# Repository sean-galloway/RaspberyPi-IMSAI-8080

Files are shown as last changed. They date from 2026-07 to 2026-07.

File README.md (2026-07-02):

# IMSPI 8080

A smart front panel for a 10" rack, styled after the IMSAI 8080, driven by a
Raspberry Pi (running an 8080/Z80 emulator such as z80pack or SIMH) over a single
USB link. An on-panel RP2040 owns all LED refresh and switch debounce and exposes
the panel to the Pi as a small register-mapped serial peripheral.

## Why a smart panel

The naive build wires every LED and switch straight back to the Pi header with
flying leads — which does not scale past ~60 I/O and turns into a harness. Instead
the panel carries its own microcontroller and driver silicon, and the Pi talks to
it the way a CPU talks to memory-mapped I/O: write the lamp registers, read the
switch registers. This decouples the panel's real-time refresh from whatever else
the Pi is doing, moves debounce and PWM off the Pi, and keeps a single 3.3V rail
with no level shifters.

## Panel layout

Matched to the physical panel (see `docs/panel-layout.svg`):

- Left block: three rows of 8 LEDs over 8 toggles
  - row 1 — address high (A15..A8)
  - row 2 — address low  (A7..A0)
  - row 3 — data          (D7..D0)
  - 8 data toggles (latching) below
- Right block: one row of 4 status LEDs over 4 command switches (momentary)

28 LEDs, 12 switches, sized to the ~220 mm usable width of a 10" rack aperture.
Because all 16 address bits are displayed even though only 8 data toggles exist,
EXAMINE looks fully authentic; address entry is byte-wise (see `docs/protocol.md`).

## Architecture

```
  Raspberry Pi 5 ── USB CDC ── RP2040 (Pico) ─┬─ SPI ──▶ 2x TLC5947  ─▶ 28 LEDs
   (emulator)                                  └─ GPIO ─▶ 2x 74HC165 ◀─ 12 switches
```

- MCU: RP2040 (Raspberry Pi Pico / Pico 2)
- LED driver: 2x TLC5947 (24ch, 12-bit PWM, constant current) daisy-chained -> 48ch, 28 used
- Switch input: 2x 74HC165 (parallel-in serial-out) daisy-chained -> 16 in, 12 used
- Link: RP2040 native USB CDC (`/dev/ttyACM0`); 4-pin UART is the wired fallback

See `docs/bom.md` for the parts list and `docs/panel-layout.md` for the bezel grid
and pitch math.

## Repo layout

```
docs/        protocol spec, BOM, panel layout + drawing
firmware/    RP2040 firmware (Pico SDK, C)
host/        Python driver + examples for the Pi side
hardware/    KiCad / mechanical notes
```

## Quick start

Firmware: see `firmware/README.md` (Pico SDK build -> drag `imspi8080.uf2` to the
Pico in BOOTSEL mode).

Host: see `host/README.md`.

```bash
cd host
pip install -e .
python examples/lamp_test.py /dev/ttyACM0
```

## Emulator integration

The panel is a clean memory-mapped-I/O seam. On each emulated CPU step, write the
LED frame (address bus, data bus, status flags) and consume any latched switch
events. z80pack and SIMH both expose CPU state and an I/O hook you can bridge to
`host/imspi`; `examples/panel_demo.py` drives the panel with a synthetic bus so you
can validate the hardware end-to-end before wiring the emulator.

## License

MIT — see `LICENSE`.

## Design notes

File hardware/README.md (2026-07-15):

# Hardware

IMSPI 8080 front-panel PCB + 3D-printed fascia for the 10" rack.

## ⬆️ To send to the fab, upload ONE folder: `jlcpcb-rev3/`

That is the only current, DRC-clean package. Everything superseded lives in `OLD/`.

```
jlcpcb-rev3/
  imspi8080-rev3-gerbers.zip   <- upload this (copper/mask/silk/paste + PTH & NPTH drill)
  imspi8080-rev3-cpl.csv       <- placement (83 SMT parts)
  imspi8080-rev3-bom.csv       <- BoM (electronics only; switches are hand-jumpered)
  README.txt                   <- step-by-step upload order + gotchas
```

Board: **204 × 99.7 mm**, 2-layer, 1.6 mm FR-4. Fully routed, 0 unconnected, 0 DRC errors.

## Current rev3 source (the design behind that package)

| File | What it is |
|---|---|
| `imspi8080_rev3.kicad_pcb` | the board (+ `.dsn`/`.ses` routing, `.kicad_pro`/`.prl`) |
| `rev3_place2.py` → `rev3_pads.py` | build chain: signal-flow placement, then bottom-edge switch landing pads |
| `rev3_routed.png` | routed board render |
| `faceplate/` | 3D-printed fascia — `gen_faceplate_3d.py` → `faceplate_3d.scad`/`.stl`, `faceplate_preview.png` |
| `design-spec.md`, `bom.csv`, `imspi8080_skidl.py` | design notes / schematic source |

**Switch scheme (rev3):** panel toggles mount on the fascia just below the board's
bottom edge and jumper straight up to a labeled solder landing-pad cluster each
(`SWD0-7` data 1×3, `SWC0-3` command 2×3; back-silk `V/Sn/G`, `Cn/G`). No connectors,
no cables, no board cutouts. The switch pads are bare/hand-soldered, so they are
excluded from the CPL/BoM.

## `OLD/` — superseded, do NOT upload

- `jlcpcb-rev1/`, `jlcpcb-rev2/` — earlier fab packages (rev1 is the one already ordered)
- `imspi8080_rev2.*`, `imspi8080.*` — earlier boards
- `rev3_voids.py`, `rev3_back.png` — the abandoned "switch-through-void" design
- earlier placement scripts, logs, notes

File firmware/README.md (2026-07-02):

# IMSPI 8080 firmware (RP2040)

Owns LED refresh (2x TLC5947), switch scan + debounce (2x 74HC165), and the
serial protocol to the Pi over native USB CDC. Built with the Raspberry Pi
Pico SDK.

## Prerequisites

- CMake >= 3.13, GNU Arm toolchain, and the Pico SDK.
- Set `PICO_SDK_PATH` to your SDK checkout, e.g.:

```bash
git clone https://github.com/raspberrypi/pico-sdk.git
cd pico-sdk && git submodule update --init && cd ..
export PICO_SDK_PATH=$PWD/pico-sdk
```

## Build

```bash
cd firmware
mkdir build && cd build
cmake ..
make -j
```

This produces `build/imspi8080.uf2`. Hold BOOTSEL on the Pico, plug it in, and
drag the `.uf2` onto the `RPI-RP2` drive.

## Wiring

Pin assignments are in `src/config.h` (RP2040 GPIO numbers). Defaults:

| Signal | GPIO | To |
|---|---|---|
| TLC SIN | 3 | first TLC5947 SIN |
| TLC SCLK | 2 | TLC5947 SCLK  |
| TLC XLAT | 4 | TLC5947 XLAT  |
| TLC BLANK | 5 | TLC5947 BLANK |
| TLC GSCLK | 6 | TLC5947 GSCLK |
| HC165 SH/LD | 10 | 74HC165 pin 1 |
| HC165 CLK | 11 | 74HC165 pin 2 |
| HC165 QH | 12 | last 74HC165 QH |

If the wrong LED chip lights up, flip `TLC_REVERSE_DEVICE_ORDER`. If switches map
backwards, flip `HC165_REVERSE_BITS`.

## Notes and things to verify against the datasheet

- The TLC5947 GSCLK is a free-running PWM (`TLC_GSCLK_HZ`, default 1 MHz) and
  BLANK is released after priming. For flicker-free updates you can additionally
  pulse BLANK once per 4096 GSCLK cycles to align the grayscale counter — not
  required for a front panel, but noted.
- Data shift is bit-banged for clarity. If you want more headroom, move SIN/SCLK
  onto a hardware SPI instance; the byte order in `tlc5947.c` stays the same.
- CRC-8 parameters must stay in sync with `host/imspi/crc8.py`.

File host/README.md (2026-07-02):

# IMSPI 8080 host driver

Python driver for the Pi side of the panel. Talks the serial protocol in
`../docs/protocol.md` to the RP2040 over USB CDC (`/dev/ttyACM0`).

## Install

```bash
cd host
python -m venv .venv && source .venv/bin/activate
pip install -e .
```

## Use

```python
from imspi import Panel

with Panel("/dev/ttyACM0") as p:
    print(p.ping())                       # (major, minor)
    p.set_bus(addr=0x1234, data=0x76, status=0b0001)  # RUN lamp on
    rep = p.poll(timeout=1.0)             # latest SwitchReport, or None
    if rep and rep.examine:               # command switch 2 (EXAMINE) pressed
        print("examine, data toggles =", hex(rep.data))
```

## Examples

```bash
python examples/lamp_test.py /dev/ttyACM0     # bring-up: sweep lamps, print switches
python examples/panel_demo.py /dev/ttyACM0    # synthetic bus + live switch echo
```

`panel_demo.py` drives the panel with a fake address/data bus and mirrors the data
toggles onto the data lamps, so you can validate the whole panel before wiring an
emulator. For z80pack/SIMH, replace the synthetic loop with the emulator's CPU
state and feed switch events back into its I/O hook.

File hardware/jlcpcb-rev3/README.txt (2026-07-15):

IMSPI 8080 rev3 — JLCPCB upload package
=======================================
Board: 204 x 99.7 mm, 2-layer, 1.6 mm FR-4, HASL. 83 SMT parts.
Fully routed, DRC-clean (0 unconnected, 0 errors).

WHAT'S DIFFERENT FROM REV1/REV2
- The panel switches are NOT on a separate bracket wired through JST connectors
  (rev1/rev2 J3/J4). Instead each switch has its own labeled solder LANDING-PAD
  cluster along the board's BOTTOM EDGE:
    SWD0..7 : 1x3 pads [V=+3V3, Sn=data common, G=GND]  (MTS-123 SPDT data toggles)
    SWC0..3 : 2x3 pads [Cn=cmd common, G=GND, +4 spare]  (MTS-223 DPDT command toggles)
  The switches mount on the fascia just below the board and jumper straight up to
  these pads. Back-silk labels every pad. These pads are BARE — hand-soldered — so
  they are excluded from the CPL/BoM (JLCPCB places nothing there).

UPLOAD ORDER
1. jlcpcb.com -> Add Gerber -> upload  imspi8080-rev3-gerbers.zip
   (auto-detects 2-layer, 204 x 99.7 mm)
2. Enable SMT Assembly -> "Assemble both sides".
3. Placement file (CPL):  imspi8080-rev3-cpl.csv   (Designator, Mid X, Mid Y, Layer, Rotation)
4. BOM:                   imspi8080-rev3-bom.csv   (83 placed parts)
5. Step through part matching; confirm each turns green. U2 flash must be the 3.3 V
   part (W25Q128JVSIQ, not the 1.8 V JW). Verify pin-1 rotations in the preview.

NOTES
- Ground is routed as traces (no plane) - fine for this low-speed panel.
- Mounting holes H1-H6 are NPTH and excluded from the CPL (correct).
- The 12 switch landing pads (SWD0-7, SWC0-3) are hand-jumpered to fascia toggles
  and are intentionally absent from the CPL/BoM.

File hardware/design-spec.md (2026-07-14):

# IMSPI 8080 controller board — design spec

Everything needed to lay the board out in KiCad and generate the manufacturing
files. Pair this with `bom.csv`. The BOM is upload-ready; the Gerbers and CPL
come out of the layout step described here.

## Board

- Panel format: **3U 10" rack face** (133.4 mm tall). 3U (not 2U) is required for
  mechanical clearance: the bezel toggles are panel-mounted with ~13 mm-deep bodies that
  stick back toward the PCB, so they ride on their own bracket below the board, wired back
  via J3/J4. (Trade-off: a 3U face reads squarer than the IMSAI's wide 2.5:1 — a fully
  faithful build wants a 19" 4U panel; see the project TODO.)
- Outline: **204 × 60 mm PCB (rev2)** — trimmed 10 mm on each axis from the rev1 214 × 70.
  The trim is **structural, not cosmetic**: it opens ~8-10 mm **clearance channels down
  each side** (and frees the band below) for the computer-carrier-plate side flanges, the
  front L-gussets, and their rail-mount hardware (see `carrier-plate-rigidity` plan and
  `TODO.md`). The 28 LEDs occupy the top ~32 mm; the ICs/connectors fill the band below.
- Stackup: 2-layer FR-4, 1.6 mm, HASL (ENIG optional for the HTSSOP pads).
- Mounting: 6× M2.5 to short bezel standoffs (see "Mounting holes" below). The outer hole
  columns (x = 8 / 196 mm) sit on the structural channels so the front L-gussets land on them.
- Assembly: two-sided SMT. Front (component/bezel side) carries the LEDs, ICs, and
  connectors; the 40 decoupling caps / resistors sit on the **back** directly under
  their ICs (ideal decoupling, GND pads land straight in the back ground plane, and
  the dense front layout de-clutters). Toggles remain off-board (wired). The small
  JLCPCB two-sided-assembly adder buys a far cleaner, routable board.

> **Rev1 (214 × 70) is already fabricated/ordered — the 204 × 60 numbers here define rev2.**
> The LED grid moved inward with the trim, so `docs/panel-layout.md` and the faceplate
> bezel windows must be regenerated to match before the faceplate is cut.

## Mounting holes

6× M2.5, NPTH, ~2.7 mm drill, electrically isolated (single-point ground kept
clean). Each gets a ~6 mm keep-out ring — no traces, pours, or parts inside it,
so the screw head/standoff base has room. Positions in mm from the board's
top-left datum (same datum as the LED grid), in LED-free zones, with the outer
columns on the structural side channels (204 × 60 rev2 board):

| Ref | X | Y  | Zone |
|-----|-----|----|---|
| H1  | 8 | 7  | top-left channel (gusset column)  |
| H2  | 131 | 7  | top, inter-block gap |
| H3  | 196 | 7  | top-right channel (gusset column) |
| H4  | 8 | 53 | bottom-left channel |
| H5  | 131 | 53 | bottom, inter-block gap |
| H6  | 196 | 53 | bottom-right channel |

Outer columns x = 8 / 196 → mirrored ~8 mm channels each side, and they are the
lines the carrier-plate front L-gussets bolt to. The mid-span holes (H2/H5) live
in the 119..147 mm gap between the left LED block (ends x=119) and the status
block (starts x=147) — keeping the strip from bowing without crowding any lamp.
Placed by `place_holes.py`, which offsets from the Edge.Cuts bbox so it is immune
to where the board sits on the sheet. Standoffs: short, **3–5 mm** brass, so the
LEDs sit just behind the bezel windows. Keep the tall parts (USB-C, microSD, JST)
at the edges, which the layout already does.

## Power tree

Two USB-C inputs, grounds bonded, 5 V rails separate.

```
USB-C #1 (J1)  VBUS 5V ──► U8 AMS1117-3.3 ──► 3V3_LOGIC ──► RP2040 IOVDD/USB/ADC,
   │                                                          TLC5947 VCC (logic),
   │ D+/D- (27R series) ──► RP2040 USB                        74HC165 VCC, SD VDD,
   │ CC1/CC2 ──► 5.1k to GND                                  pull-ups
   └ GND ──────────────────────────────┐
                                        ├── common GND
USB-C #2 (J2)  VBUS 5V ──► U9 AMS1117-3.3 ──► 3V3_LED ──► 28x LED anodes
   │ CC1/CC2 ──► 5.1k to GND            │
   └ GND ───────────────────────────────┘   (LED cathodes sink into TLC5947 → GND)
```

- RP2040 core (1.1 V) is generated by its internal LDO — just decouple DVDD.
- 3V3_LED at 3.3 V (not 5 V) keeps TLC5947 dissipation low: ~1.3 V drop/channel
  instead of ~3 V. If you ever want brighter lamps off the Pi's budget, J2 is a
  dedicated feed so the LED current never touches the logic side.
- Bulk 10 µF on each of: 3V3_LOGIC, 3V3_LED, and VBUS(J1). 100 nF at every IC.

## Net / connection map (RP2040 GPIO)

Dedicated-function pins (USB, QSPI, XIN/XOUT, SWD) per the RP2040 reference
design. Peripheral GPIO assignment:

| GPIO | Net | To |
|---|---|---|
| GP2 | TLC_SCLK | U3/U4 SCLK (SPI0 SCK) |
| GP3 | TLC_SIN | U3 SIN (SPI0 TX); U3 SOUT→U4 SIN|
| GP4 | TLC_XLAT | U3/U4 XLAT |
| GP5 | TLC_BLANK | U3/U4 BLANK |
| GP6 | TLC_GSCLK | U3/U4 GSCLK (PWM) |
| GP7 | HC_PLOAD | U5/U6 SH/LD |
| GP8 | HC_CLK | U5/U6 CLK |
| GP9 | HC_QH | U6 QH (chain output) |
| GP10 | SD_SCK | U7 CLK (SPI1 SCK) |
| GP11 | SD_MOSI | U7 CMD (SPI1 TX) |
| GP12 | SD_MISO | U7 DAT0 (SPI1 RX) |
| GP13 | SD_CS | U7 DAT3/CS (SPI1 CSn) |
| GP14-22| spare | broken out to J5 area / testpoints |

TLC5947 drivers share one SPI0 daisy-chain; the two 74HC165s share a bit-banged
chain; the SD card is on its own SPI1 so a card access can't stall lamp refresh.

### LED channel map (into the TLC5947 chain)

- U3 (device 0): ch0-7 = addr A15..A8, ch8-15 = addr A7..A0, ch16-23 = data D7..D0
- U4 (device 1): ch24-27 = status 0..3 (ch28-47 spare)

### Switch header pinout

J3 — data bank (S10B-XH-A), MTS-102 SPDT ON-ON, each common → 74HC165 input,
throws bussed to 3V3/GND at the bezel (no pull-ups needed):

```
1:3V3  2:SW0  3:SW1  4:SW2  5:SW3  6:SW4  7:SW5  8:SW6  9:SW7  10:GND
```

J4 — command bank (S6B-XH-A), MTS-123 center-off momentary, each common →
74HC165 input, one throw bussed to GND at the bezel; **pull-ups on-board** (R
group) define the released state:

```
1:GND  2:CMD0  3:CMD1  4:CMD2  5:CMD3  6:spare
```

Both are side-entry (right-angle) so the wire housings mate parallel to the
board — place them along the bezel-facing edge, openings outward.

## Layout plan

1. LEDs first, locked to the bezel grid from `docs/panel-layout.md` (3 rows of 8
   over the 8 data columns + 4 status), 15 mm column pitch (aligns lamps over toggles). Their positions are
   fixed by the bezel; everything else routes around them.
2. RP2040 + flash + crystal as a tight cluster (follow the reference layout;
   crystal and QSPI traces short). TLC5947s near the LED field to keep the 28
   LED-cathode traces short. 74HC165s near J3/J4.
3. USB-C J1 and J2 at accessible board edges (Pi cable to J1; LED supply to J2).
   microSD U7 at an edge with the slot opening reachable through a bezel cutout.
4. J3/J4 right-angle headers along the switch-facing edge.
5. Star the two 5 V rails; single solid ground pour bonding both USB-C grounds.

## Design rules (JLCPCB 2-layer, economy-safe)

- Trace/space ≥ 0.2 mm (0.15 mm capable if needed); LED-cathode and signal nets 0.25 mm.
- Via 0.3 mm drill / 0.6 mm pad; annular ring ≥ 0.13 mm.
- Board-edge clearance ≥ 0.3 mm; silkscreen ≥ 0.15 mm.
- Add fiducials (3× on the assembled side) for the pick-and-place.

## Manufacturing outputs (what to upload)

Ordered at **jlcpcb.com** ("Order Now" / Add Gerber). Three files:

1. **Gerbers ZIP** — from KiCad: Plot (all copper, mask, silk, edge cuts) +
   Generate Drill Files, zipped. *(produced by the layout step)*
2. **BOM CSV** — `hardware/bom.csv` in this repo. *(ready now)*
3. **CPL / pick-and-place CSV** — KiCad → Fabrication Outputs → Component
   Placement (.pos), columns Designator/Mid X/Mid Y/Rotation/Layer.
   *(produced by the layout step)*

At upload, toggle SMT Assembly, choose the assembled side (top), and step through
component matching — confirm each part turns green; watch for any LED or socket
flagged **Standard Only** (forces Standard PCBA) and swap if you want Economic.
Verify rotations in the placement preview (pin-1 dots) before paying.

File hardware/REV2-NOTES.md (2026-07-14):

# IMSPI 8080 — rev2 (204 × 60) re-layout

Rev2 trims the board 10 mm on each axis (rev1 was 214 × 70) to open the structural
side channels the computer-carrier-plate flanges/gussets need — see `design-spec.md`
and `../TODO.md`. **Rev1 is already fabricated/ordered; these are the rev2 files.**

## What's ready (generated headless)
| File | State |
|---|---|
| `imspi8080_rev2.kicad_pcb` | Board re-placed to 204 × 60 + **89/90 nets routed** |
| `rev2_place.py` | The placement driver (reproducible): resizes the outline, positions every footprint, rips up old routing. Run with `/usr/bin/python3 rev2_place.py` |
| `rev2_check.py` | Overlap / off-board checker (0 / 0 on the current board) |
| `imspi8080_rev2.dsn` / `.ses` | Specctra export + Freerouting result |
| `jlcpcb-rev2/imspi8080-rev2-cpl.csv` | Pick-and-place, 85 parts (45 top / 40 bottom), holes excluded |
| `jlcpcb-rev2/imspi8080-rev2-bom.csv` | BOM — **same 85 parts as rev1** (resize changes positions, not parts) |
| `place_leds.py`, `place_holes.py` | Updated to the rev2 grid (LEDs 14–119 / status 147–192, rows 6/18/30; holes 8/196) |

How it was built: `SKiDL netlist → rev2_place.py (placement) → Specctra DSN →
Freerouting 1.9.0 (headless, 0.15/0.13 mm rules) → SES import`. Placement is 0 overlaps,
0 off-board. Everything fits inside 204 × 60 with ~10 mm side channels.

## What YOU finish in KiCad (2 quick touch-ups, like rev1)
Open `imspi8080_rev2.kicad_pcb` in pcbnew, then:

1. **Route one trace** — the USB D− hop Freerouting couldn't thread through the RP2040's
   0.4 mm-pitch escape: **R6 pad 2 → U1 pad 46** (net `N$8`). Use the interactive router;
   it needs one via (R6 is on the back, U1.46 on the front). ~1 minute.
2. **Nudge one via** — the `SD_MISO` via near the bottom-right corner sits 0.18 mm from the
   board edge (rule is 0.3 mm). Drag it ~0.2 mm inward (KiCad will drag its tracks with it).
3. **DRC** → should be clean (Tools → DRC).
4. **Export fab**: Plot all copper + mask + silk + Edge.Cuts, Generate Drill Files, zip →
   Gerbers. Fabrication Outputs → Component Placement (.pos) → or just reuse
   `jlcpcb-rev2/imspi8080-rev2-cpl.csv`. BOM = `jlcpcb-rev2/imspi8080-rev2-bom.csv`.
5. **JLCPCB**: same as rev1 — **Standard PCBA, double-sided** (45 top + 40 back caps).

## BOM note (parts unchanged, but sync your JLCPCB swaps)
Resizing does **not** change the parts list. The rev2 BOM is the rev1 BOM. Separately,
the repo BOM still shows the *original* parts — it never got the JLCPCB replace-parts
swaps (SW1/SW2 → HX 3×4×2 tactile, U2 flash confirm, J5 DNP). Tell me your final choices
and I'll reconcile `bom.csv` + both fab BOMs.

## Faceplate (signage recesses)
`faceplate/gen_front_panel.py` (grabbed from jetson-marker-turret) regenerates
`faceplate/imspi_panel_front.svg` — the engraved legend + LED window slots (the paint
recesses), now **aligned to the rev2 LED grid**. Regenerate: `python3 gen_front_panel.py`.
The LED field is left-of-center after the trim (status block pulled in) — re-center by
adjusting `CONTENT_DX` if wanted (keep it in sync with the turret `rack_shelf.scad` mount).

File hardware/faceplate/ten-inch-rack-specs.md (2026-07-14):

# 10″ Rack — Panel & Mounting-Hole Specs

Reference for any front panel that mounts in the ground-station rack
(DeskPi RackMate T2, BOM #52). Use these numbers for rack-mount faces —
the compute shelf (#61), blank/vent panels (#59), and the IMSAI/IMSPI
fascia (built in the separate panel repo).

**Source:** manufacturer mechanical drawing, cross-checked against a real
10″ 12-port keystone patch panel (254 mm overall, 238 mm mount-hole span,
214 mm aperture). Confirm against your own rails before cutting — the oval
slots absorb small differences.

## Panel envelope

| Dimension | Value |
|---|---|
| Panel outer width | **254 mm** |
| 1U height | **44 mm** (1.73 in) |
| N-U panel height | **N × 44 mm** (2U = 88, 3U = 132) |
| Front-face thickness (printed) | 4–5 mm typical |

## Mounting-hole geometry

| Dimension | Value | Notes |
|---|---|---|
| Hole horizontal center-to-center | **238 mm** | across the panel |
| Hole inset from each **side** edge | **8 mm** | = (254 − 238) / 2 |
| Hole vertical center-to-center, **within 1U** | **33 mm** | |
| Hole inset from **top/bottom** of a 1U | **5.5 mm** | = (44 − 33) / 2 |
| Slot shape | **horizontal oval**, **9.33 W × 6.77 H mm** | oval = side-to-side rail-fit adjustment |

- Holes/slots come in a **column at x = 8 mm and x = 246 mm** (both side edges).
- Vertically they repeat per 1U: each 1U has a pair at **5.5 mm** from its top
  and bottom edges (33 mm apart).

## Clear aperture (usable opening)

| Face | Usable width | Usable height |
|---|---|---|
| any | **214 mm** | 1U ≈ 33 mm · 2U ≈ 77 mm · 3U ≈ 122 mm |

Width is set by the mounting-hole span, not the electronics.

## Worked example — a 3U face (132 mm tall)

Four corner mounting slots (what the compute-bay design uses):

| Slot | x (from left) | z (from bottom) |
|---|---|---|
| top-left | 8 | 126.5 |
| top-right | 246 | 126.5 |
| bottom-left | 8 | 5.5 |
| bottom-right | 246 | 5.5 |

(z = 5.5 from the bottom edge, and 132 − 5.5 = 126.5 from it for the top.)
If your rails are tapped at every U, you may add mid-height slots on the
same 33-mm-in-1U pattern; 4 corners is sufficient for a printed compute bay.

## OpenSCAD reference

```scad
// 10" rack mounting geometry
face_width    = 254;
U             = 44;
rail_hole_dx  = 238;                       // horizontal C-C
hole_cc_v     = 33;                         // vertical C-C within 1U
slot_w        = 9.33;                       // oval slot W
slot_h        = 6.77;                       // oval slot H
slot_side_ctr = (face_width - rail_hole_dx)/2;   // 8 mm
slot_tb_ctr   = (U - hole_cc_v)/2;               // 5.5 mm

// one horizontal oval slot, cut through a face of thickness `th` (bore along +Y)
module rack_slot(th, eps = 0.01) {
    off = (slot_w - slot_h)/2;
    hull() for (dx = [-off, off])
        translate([dx, -eps, 0]) rotate([-90,0,0])
            cylinder(h = th + 2*eps, d = slot_h, $fn = 48);
}

// 4 corner slots for a panel `panel_U` high, thickness `th`
module rack_slots_4corner(panel_U, th) {
    panel_h = panel_U * U;
    for (sx = [slot_side_ctr, face_width - slot_side_ctr])
        for (sz = [slot_tb_ctr, panel_h - slot_tb_ctr])
            translate([sx, 0, sz]) rack_slot(th);
}
```

## Notes

- **Oval, not round:** the horizontal ovals let the panel slide ±~1.5 mm to
  line up with imperfect rails — orient the long axis horizontal.
- **Fasteners:** M6 rack screws (with cage/clip nuts) are typical for these
  10″ racks; confirm your rack's thread/cage-nut style.
- **RackMate T2 interior depth:** ~260 mm (≈10.23″) — leave room behind the
  face for cabling/service loops.

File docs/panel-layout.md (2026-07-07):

# Panel layout

See `panel-layout.svg` for the drawing. This documents the dimensions behind it.

## Width budget

A 10" 1U rack aperture measures **214 mm** wide × 33 mm high (verified against an
actual 10" 12-port keystone patch panel: 254 mm overall, 238 mm mount-hole span,
214 mm aperture). Width is set by toggle finger-clearance, not the electronics —
the LEDs are trivial. **Height forces 2U:** the lamps-over-toggles stack needs the
~77 mm usable aperture of a 2U face; it does not fit 1U's 33 mm.

## Blocks

Left block (8 columns):

| Row | Lamps | Element |
|-----|---|---|
| 1 | 8 — address high A15..A8 | 3 mm LED |
| 2 | 8 — address low  A7..A0  | 3 mm LED |
| 3 | 8 — data D7..D0 | 3 mm LED |
| — | 8 — data toggles | latching toggle |

Right block (4 columns):

| Row | Lamps | Element |
|-----|---|---|
| 1 | 4 — status | 3 mm LED |
| — | 4 — command | momentary toggle |

## Pitch math (fits 214 mm × 2U)

Columns must align vertically (LEDs sit above toggles), so toggle pitch governs
each block's column spacing.

- toggle pitch: ~15 mm center-to-center (fits 8 + 4 toggles in the 10" width;
  MTS mini-toggle bodies clear at this pitch)
- left block, 8 columns: 7 x 15 mm = **105 mm** span
- right block, 4 columns: 3 x 15 mm = **45 mm** span
- remaining for center gap + two side margins: 214 - 105 - 45 = **64 mm**

Comfortable fit horizontally. Vertically, the LED rows use **12 mm** pitch (centers
at y = 10 / 22 / 34), so the three-row lamp field is ~30 mm; adding the toggle row
below plus a branding strip is why this is a **2U** face (~77 mm usable), not 1U.

## Mechanical: the standoff stack

The one dimension to get right before fabbing the PCB:

```
printed bezel  ─┐
                │  toggle bushing length  +  panel thickness
PCB (toggles) ──┘  must equal the PCB-to-bezel standoff height
```

Board-mounted toggles solder to the PCB; their threaded bushings pass through the
bezel. If the standoff height doesn't match the bushing length (minus bezel
thickness), the bushings either don't reach the front face or protrude too far.
LED body length sets the same constraint for the LED domes. Measure the exact
bushing length and paddle-cap depth of the toggles you buy, then set the standoff
height and bezel thickness to suit — there is no fixing this after fab.

## Bezel windows + diffuser film

Rather than 28 individual holes, cut one horizontal window slot per LED row and
back it with smoked/diffuser film — the lamps read as glowing dots and the film
hides the PCB, unlit LEDs, and traces when off ("black glass until lit").

Slot centers align with the LED rows, so they inherit the 15 mm grid. Coordinates
in mm on the shared datum (LED rows at y = 10 / 22 / 34; left block x = 15..120,
status block x = 160..205):

| Window | X span | Y center | Size (W × H) |
|---|---|---|---|
| Row 1 addr hi | 10 – 125 | 10 | ~115 × 6 mm |
| Row 2 addr lo | 10 – 125 | 22 | ~115 × 6 mm |
| Row 3 data | 10 – 125 | 34 | ~115 × 6 mm |
| Status | 155 – 210 | 22 | ~55 × 6 mm |

- 6 mm slot height leaves ~6 mm of bezel between rows (12 mm row pitch) — enough
  material to stay rigid on a printed face.
- Film: dark-tinted diffusing acrylic/polycarbonate or LED diffusion sheet,
  0.5–1 mm, cut ~5 mm oversize per window and bonded to the **back** of the bezel.
- Tint eats brightness — plan to lower the TLC5947 IREF resistor a little to push
  more per-LED current (free on the dedicated LED rail). Swatch-test tint darkness
  against a lit LED before committing: too dark = weak lamps, too light = board
  shows when off.
- Alternative: one big 115 × 30 mm window over all three left-block rows backed by
  film — simplest cut, but less rigid and loses the segmented IMSAI slot look.

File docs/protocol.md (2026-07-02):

# IMSPI 8080 serial protocol

Version 0.1.0

The Pi (host) and the panel (RP2040) exchange fixed, byte-oriented frames over the
RP2040's native USB CDC (or a 4-pin UART fallback). Baud is nominal over CDC.
The panel is treated as a register-mapped peripheral: the host writes lamp
registers, the panel reports switch registers.

## Framing

Every frame is:

```
[SOF] [CMD] [payload ...] [CRC8]
```

- `SOF` — start-of-frame, direction-specific (lets each side resync)
  - host -> panel: `0xA5`
  - panel -> host: `0x5A`
- `CMD` — command/response byte (see tables)
- `CRC8` — over every byte in the frame *except* the CRC byte itself
  (i.e. from `SOF` through the last payload byte)

Frame length is fixed per `CMD`, so a receiver reads `SOF`, then `CMD`, then the
known number of remaining bytes. On CRC failure or unknown `CMD`, discard bytes
until the next valid `SOF`.

### CRC8

CRC-8, polynomial `0x07`, init `0x00`, no input/output reflection, no final XOR
(the classic "CRC-8/SMBUS" parameters). Reference implementations:
`firmware/src/crc8.c` and `host/imspi/crc8.py` — they are byte-for-byte identical.

## Host -> panel commands

### `0x01` LED update (8 bytes)

Writes the full lamp state in one frame.

| Byte | Field | Meaning |
|---|---|---|
| 0 | `0xA5` | SOF |
| 1 | `0x01` | CMD |
| 2 | `ADDR_HI` | address bus A15..A8 (bit7 = A15) |
| 3 | `ADDR_LO` | address bus A7..A0 |
| 4 | `DATA` | data bus D7..D0 |
| 5 | `STATUS`  | status lamps, bits 0..3 used (see below) |
| 6 | `BRIGHT`  | global brightness 0..255 (maps to 12-bit)  |
| 7 | `CRC8` | |

`STATUS` bit assignment (default, firmware-configurable):

| bit | lamp |
|-----|---|
| 0 | RUN |
| 1 | WAIT |
| 2 | HLDA |
| 3 | INT/PWR|

### `0x02` lamp test (4 bytes)

`[0xA5][0x02][ON][CRC8]` — `ON != 0` drives all lamps full on; `0` returns to the
last LED-update state. Useful for bring-up and a boot self-test.

### `0x03` set brightness (4 bytes)

`[0xA5][0x03][LEVEL][CRC8]` — global brightness 0..255 without changing lamp state.

### `0x7F` ping (3 bytes)

`[0xA5][0x7F][CRC8]` — panel replies with `0xC0` version.

## Panel -> host responses

### `0x81` switch report (6 bytes)

Sent on any switch change and on a periodic heartbeat.

| Byte | Field | Meaning |
|---|---|---|
| 0 | `0x5A` | SOF |
| 1 | `0x81` | CMD |
| 2 | `SW_DATA` | 8 data toggle levels (bit i = toggle i) |
| 3 | `SW_CMD`  | 4 command switch levels, bits 0..3 |
| 4 | `EVENTS`  | latched rising edges on command switches 0..3 |
| 5 | `CRC8` | |

`SW_DATA` are latching toggles, reported as levels. The 4 command switches are
momentary (spring-return); their *levels* are in `SW_CMD`, but the important field
is `EVENTS`: a bit set means that command switch saw a press (rising edge) since
the last report. The panel latches edges so a fast press between two host polls is
never lost, then clears them once reported.

Default command-switch map (firmware-configurable):

| bit | switch | action |
|-----|---|---|
| 0 | RUN / STOP  | toggle run state |
| 1 | SINGLE STEP | advance one instruction |
| 2 | EXAMINE | load address from data toggles  |
| 3 | DEPOSIT | store data toggles at address |

Four physical command switches give four momentary actions. The classic 8-function
IMSAI set (EXAMINE/EXAMINE-NEXT, DEPOSIT/DEPOSIT-NEXT, RESET, etc.) can be layered
by treating a held toggle as a modifier, or by wiring 3-position `(on)-off-(on)`
momentaries to two `74HC165` inputs each. That is host/firmware policy — the wire
protocol just carries levels + edges.

### `0xC0` version (5 bytes)

`[0x5A][0xC0][VER_MAJ][VER_MIN][CRC8]` — reply to ping.

## Byte-wise address entry

Only 8 data toggles exist, so a 16-bit EXAMINE address is entered in two gestures.
Suggested host convention:

1. set the 8 data toggles to the high byte, pulse EXAMINE with the RUN/STOP toggle
   held (modifier) -> host loads A15..A8
2. set the low byte, pulse EXAMINE normally -> host loads A7..A0 and examines

All 16 address lamps still display the full latched address, so the panel *reads*
exactly like a real IMSAI even though entry is byte-wise.

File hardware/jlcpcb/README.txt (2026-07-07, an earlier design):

IMSPI 8080 — JLCPCB upload package
==================================
Board: 214 x 70 mm, 2-layer, 1.6 mm FR-4, HASL. 85 SMT parts (45 top, 40 bottom).

UPLOAD ORDER
1. jlcpcb.com -> Order Now / Add Gerber -> upload  imspi8080-gerbers.zip
   (auto-detects 2-layer, 214 x 70 mm)
2. Enable SMT Assembly -> "Assemble both sides".
3. Placement file (CPL):  imspi8080-cpl.csv   (Designator, Mid X, Mid Y, Layer, Rotation)
4. BOM:                   imspi8080-bom.csv
5. Step through part matching; confirm each turns green. Watch for any LED/socket
   flagged "Standard Only". Verify pin-1 rotations in the preview before paying.

NOTES
- Ground is routed as traces (no plane) - fine for this low-speed panel.
- Mounting holes H1-H6 are NPTH and excluded from the CPL (correct).
- Mechanical: mounts in a 3U 10" face; toggles go on a separate bracket wired to J3/J4.

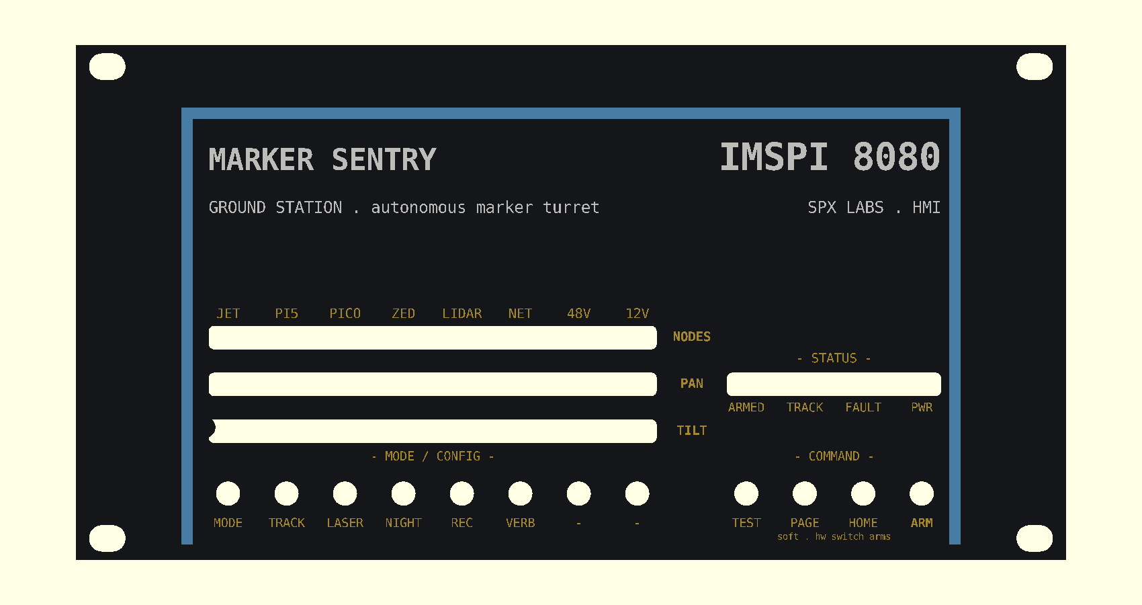
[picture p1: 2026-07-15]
hardware/faceplate/faceplate_preview.png

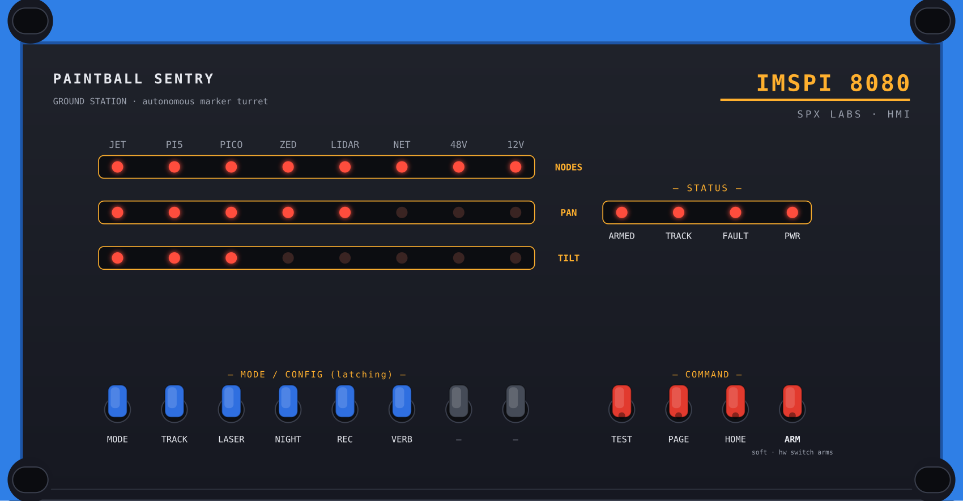
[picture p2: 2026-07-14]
hardware/faceplate/imspi_panel_front.png

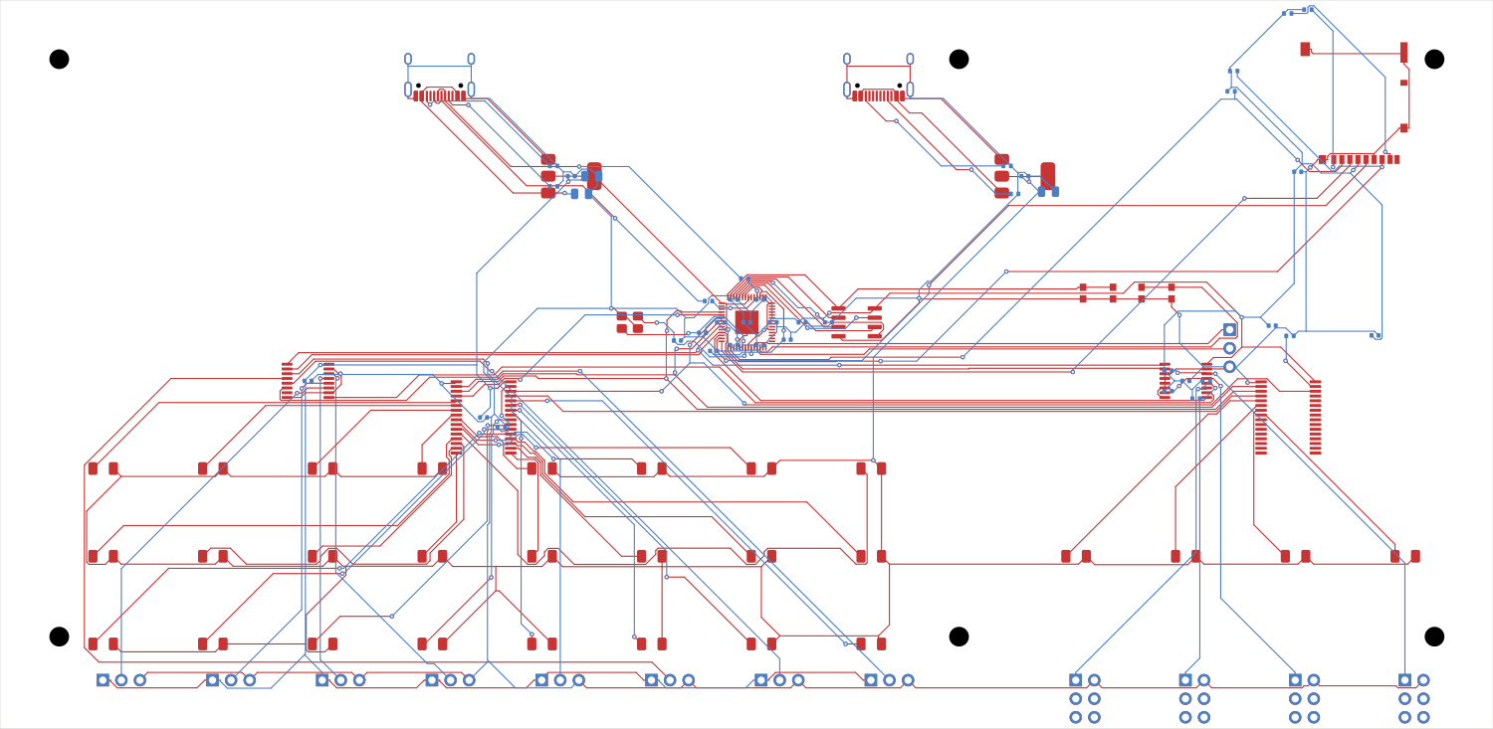
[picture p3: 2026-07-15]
hardware/rev3_routed.png

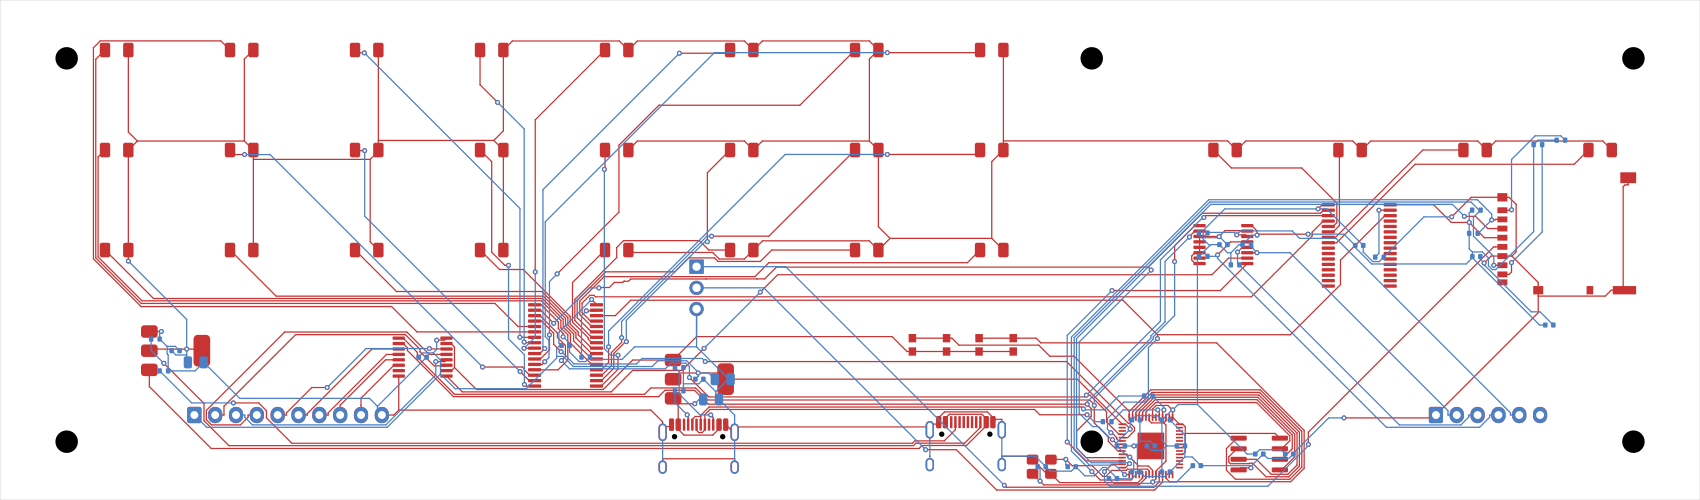
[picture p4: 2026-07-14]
hardware/rev2-routed.png

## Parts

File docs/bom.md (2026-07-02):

# Bill of materials

Quantities are for one panel. Part numbers are representative — substitute freely,
the design only assumes the interface (SPI-ish shift for the drivers, PISO for the
switches).

## Active

| Qty | Part | Role | Notes |
|-----|---|---|---|
| 1 | Raspberry Pi Pico / Pico 2 | RP2040/RP2350 panel controller | board-mount on castellations or socket |
| 2 | TLC5947 | 24ch 12-bit PWM constant-current LED driver  | daisy-chained -> 48ch, 28 used |
| 2 | 74HC165 | 8-bit parallel-in / serial-out shift register| daisy-chained -> 16 in, 12 used |

One TLC5947 covers the 24 data lamps; the second covers the 4 status lamps (20
channels spare — usable for per-lamp PWM effects). Alternatively drive the 4 status
LEDs from RP2040 GPIO + resistors and fit a single TLC5947, at the cost of
non-uniform firmware.

## Panel components

| Qty | Part | Role | Notes |
|-----|---|---|---|
| 28  | 3 mm diffused red LED | address/data/status | 24 data + 4 status |
| 8 | SPDT mini/subminiature toggle, on-off or on-on | data toggles (latching) | subminiature bushing if pitch is tight |
| 4 | momentary toggle, `(on)-off` or `(on)-off-(on)` | command switches | spring-return |
| 8+4 | 3D-printed paddle caps | IMSAI look | over the bat handles |

## Passives / glue

| Qty | Part | Role |
|-----|---|---|
| 2 | Iref resistor (~2.2–3 kΩ) | one per TLC5947; sets per-channel current (~15–25 mA) |
| ~6  | 100 nF ceramic | one decoupling cap per IC |
| 1 | 10 µF ceramic/tant | bulk on 3.3V rail |
| 2 | 10 kΩ resistor network (SIP) | pulls on the 74HC165 inputs |
| 1 | 4-pin header | UART fallback (optional; USB CDC is primary) |

## Rails

Run RP2040, both TLC5947s, and both 74HC165s at **3.3 V** — no level shifters
anywhere. Red LED forward voltage (~1.8–2.0 V) is fine on a 3.3 V LED supply, and
the TLC5947 sets current independent of the logic rail.

## PCB order

- 2-layer, 1.6 mm, HASL is fine; ENIG if you want flat pads for hand-soldering the
  TSSOP TLC5947.
- Board outline = panel inner dimension; add standoff holes matched to the printed
  shell.
- **Board-mount the toggles and LEDs.** The critical mechanical number is the
  PCB-to-bezel standoff height: it must match the toggle bushing length and LED body
  length so bushings/domes protrude correctly through the printed face. Lock this in
  CAD before routing — see `docs/panel-layout.md`.
- Component origins locked to the bezel hole grid (LEDs under window holes, toggle
  cutouts under bushings). Design the bezel hole pattern first, export positions,
  then place footprints to that grid.

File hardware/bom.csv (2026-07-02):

Comment | Designator | Footprint | Qty | MPN / suggested part | Notes
RP2040 | U1 | QFN-56 (7x7mm) | 1 | RP2040 | MCU. Copy RP2040 minimal reference design. Extended part.
QSPI Flash 16MB | U2 | SOIC-8 | 1 | W25Q128JVSIQ | Boot flash (firmware lives here). Basic/common.
12MHz crystal | Y1 | SMD-3225-4P | 1 | 12MHz 20pF | Core clock. Basic. Load caps C_Y1a/b.
TLC5947 24ch LED driver | U3;U4 | HTSSOP-32 | 2 | TLC5947DAP | LED drivers, daisy-chained. Extended part (1 line = both).
74HC165 PISO shift reg | U5;U6 | TSSOP-16 | 2 | SN74HC165PWR | Switch inputs, daisy-chained.
microSD socket push-pull | U7 | SMD push-pull | 1 | microSD TF push-pull | Data storage (optional). Pick a JLCPCB-library SMD socket.
AMS1117-3.3 | U8 | SOT-223 | 1 | AMS1117-3.3 | 3.3V logic rail from USB-C #1 VBUS. Basic.
AMS1117-3.3 | U9 | SOT-223 | 1 | AMS1117-3.3 | 3.3V LED anode rail from USB-C #2 VBUS (keeps drivers cool).
USB-C receptacle 16P | J1 | USB-C 16P SMD | 1 | TYPE-C-31-M-12 | Power + data to the Pi. 2x CC resistors + 2x D series R.
USB-C receptacle 16P | J2 | USB-C 16P SMD | 1 | TYPE-C-31-M-12 | Dedicated LED power only (VBUS+GND+CC). No data lines.
JST-XH 10P right-angle | J3 | JST S10B-XH-A | 1 | S10B-XH-A | Data-toggle bank header (8 sig + 3V3 + GND). Side entry.
JST-XH 6P right-angle | J4 | JST S6B-XH-A | 1 | S6B-XH-A | Command-switch bank header (4 sig + rail + spare). Side entry.
SWD header 1x3 | J5 | 1x3 2.54mm | 1 | header 1x3 | Debug/reflash (optional). Can be pads only.
Tactile button | SW1;SW2 | SMD tactile 4P | 2 | tactile 3x4mm | SW1=BOOTSEL, SW2=RUN/reset.
LED red 1206 | D1;D2;D3;D4;D5;D6;D7;D8;D9;D10;D11;D12;D13;D14;D15;D16;D17;D18;D19;D20;D21;D22;D23;D24;D25;D26;D27;D28 | LED-1206 | 28 | red 1206 diffused | No series resistors (TLC5947 is constant-current). Check PCBA type is not Standard-Only if you want Economic.
5.1k | R1;R2;R3;R4 | R0402 | 4 | 5.1k 0402 | USB-C CC pulldowns: 2 per connector (J1,J2).
27 | R5;R6 | R0402 | 2 | 27R 0402 | USB D+/D- series resistors (J1 data only).
2.4k | R7;R8 | R0402 | 2 | 2.4k 0402 | TLC5947 IREF (sets per-LED current ~15mA; raise R to lower current/heat).
10k | R9;R10;R11;R12;R13;R14;R15;R16;R17;R18 | R0402 | 10 | 10k 0402 | Pull-ups: SD CS+data (4), command-switch inputs (4), spares (2).
100nF | C1;C2;C3;C4;C5;C6;C7;C8;C9;C10;C11;C12;C13;C14;C15 | C0402 | 15 | 100nF 0402 | Per-IC decoupling (RP2040 needs several, TLC5947 x2, 165 x2, flash, SD, regs).
1uF | C16;C17;C18;C19 | C0402 | 4 | 1uF 0402 | RP2040 core (1.1V) decoupling + SD socket local.
10uF | C20;C21;C22 | C0805 | 3 | 10uF 0805 | Bulk on 3.3V logic, LED rail, and USB VBUS.
15pF | C23;C24 | C0402 | 2 | 15pF 0402 | Crystal load caps (tune to crystal spec).

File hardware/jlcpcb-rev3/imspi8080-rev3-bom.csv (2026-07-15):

Comment | Designator | Footprint
RP2040 | U1 | QFN-56 (7x7mm)
QSPI Flash 16MB | U2 | SOIC-8
12MHz crystal | Y1 | SMD-3225-4P
TLC5947 24ch LED driver | U3,U4 | HTSSOP-32
74HC165 PISO shift reg | U5,U6 | TSSOP-16
microSD socket push-pull | U7 | SMD push-pull
AMS1117-3.3 | U8 | SOT-223
AMS1117-3.3 | U9 | SOT-223
USB-C receptacle 16P | J1 | USB-C 16P SMD
USB-C receptacle 16P | J2 | USB-C 16P SMD
SWD header 1x3 | J5 | 1x3 2.54mm
Tactile button | SW1,SW2 | SMD tactile 4P
LED red 1206 | D1,D2,D3,D4,D5,D6,D7,D8,D9,D10,D11,D12,D13,D14,D15,D16,D17,D18,D19,D20,D21,D22,D23,D24,D25,D26,D27,D28 | LED-1206
5.1k | R1,R2,R3,R4 | R0402
27 | R5,R6 | R0402
2.4k | R7,R8 | R0402
10k | R9,R10,R11,R12,R13,R14,R15,R16 | R0402
100nF | C1,C2,C3,C4,C5,C6,C7,C8,C9,C10,C11,C12,C13,C14,C15 | C0402
1uF | C16,C17,C18,C19 | C0402
10uF | C20,C21,C22 | C0805
15pF | C23,C24 | C0402

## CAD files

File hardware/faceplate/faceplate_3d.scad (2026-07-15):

$fn=48; FACE_W=254.0; FACE_H=132.0; TH=4.0; RECESS=0.7; eps=0.05;
STANDOFF=3.5; BOSS_OD=5.5; SCREW_PILOT=2.1; FRONT_WALL=1.0;
mounts=[[33.00,113.00],[156.00,113.00],[221.00,113.00],[33.00,34.00],[156.00,34.00],[221.00,34.00]];
module bosses(){ for(m=mounts) translate([m[0],m[1],-STANDOFF]) cylinder(h=STANDOFF+eps,d=BOSS_OD); }
module screw_blind(){ for(m=mounts) translate([m[0],m[1],-STANDOFF-1]) cylinder(h=STANDOFF+1+TH-FRONT_WALL,d=SCREW_PILOT); }
module rrect(w,h,r){ hull() for(sx=[-1,1],sy=[-1,1]) translate([sx*(w/2-r),sy*(h/2-r)]) circle(r); }
module label(x,y,s,sz,ha,bold){ translate([x,y,TH-RECESS]) linear_extrude(RECESS+eps)
  text(s,size=sz,halign=ha,valign="baseline",font=bold?"DejaVu Sans Mono:style=Bold":"DejaVu Sans Mono"); }
module thru_rrect(x,y,w,h,r){ translate([x,y,-1]) linear_extrude(TH+2) rrect(w,h,r); }
module thru_circ(x,y,d){ translate([x,y,-1]) linear_extrude(TH+2) circle(d/2); }
module frame_recess(){ translate([0,0,TH-RECESS]) linear_extrude(RECESS+eps) union(){
    translate([27,4.0]) square([3.0,112]);            // left bar
    translate([224.0,4.0]) square([3.0,112]);         // right bar
    translate([27,113.0]) square([200,3.0]); } }    // top bar (open bottom)
module cuts(){ union(){
  frame_recess();
  label(39.00,62.00,"JET",2.5,"center",false);
  label(54.00,62.00,"PI5",2.5,"center",false);
  label(69.00,62.00,"PICO",2.5,"center",false);
  label(84.00,62.00,"ZED",2.5,"center",false);
  label(99.00,62.00,"LIDAR",2.5,"center",false);
  label(114.00,62.00,"NET",2.5,"center",false);
  label(129.00,62.00,"48V",2.5,"center",false);
  label(144.00,62.00,"12V",2.5,"center",false);
  label(194.50,50.60,"- STATUS -",2.4,"center",false);
  label(172.00,38.00,"ARMED",2.3,"center",false);
  label(187.00,38.00,"TRACK",2.3,"center",false);
  label(202.00,38.00,"FAULT",2.3,"center",false);
  label(217.00,38.00,"PWR",2.3,"center",false);
  label(158.00,56.10,"NODES",2.4,"center",true);
  label(158.00,44.10,"PAN",2.4,"center",true);
  label(158.00,32.10,"TILT",2.4,"center",true);
  label(91.50,25.50,"- MODE / CONFIG -",2.3,"center",false);
  label(194.50,25.50,"- COMMAND -",2.3,"center",false);
  label(39.00,8.40,"MODE",2.3,"center",false);
  label(54.00,8.40,"TRACK",2.3,"center",false);
  label(69.00,8.40,"LASER",2.3,"center",false);
  label(84.00,8.40,"NIGHT",2.3,"center",false);
  label(99.00,8.40,"REC",2.3,"center",false);
  label(114.00,8.40,"VERB",2.3,"center",false);
  label(129.00,8.40,"-",2.3,"center",false);
  label(144.00,8.40,"-",2.3,"center",false);
  label(172.00,8.40,"TEST",2.3,"center",false);
  label(187.00,8.40,"PAGE",2.3,"center",false);
  label(202.00,8.40,"HOME",2.3,"center",false);
  label(217.00,8.40,"ARM",2.3,"center",true);
  label(194.50,5.20,"soft . hw switch arms",1.7,"center",false);
  label(34.00,100.00,"MARKER SENTRY",5.5,"left",true);
  label(222.00,100.00,"IMSPI 8080",7.0,"right",true);
  label(34.00,89.00,"GROUND STATION . autonomous marker turret",3.0,"left",false);
  label(222.00,89.00,"SPX LABS . HMI",3.0,"right",false);
  // LED windows (through)
  thru_rrect(91.50,57.00,115.00,6.0,1.4);
  thru_rrect(91.50,45.00,115.00,6.0,1.4);
  thru_rrect(91.50,33.00,115.00,6.0,1.4);
  thru_rrect(194.50,45.00,55.00,6.0,1.4);
  // toggle holes + ear slots (through) — mounts are BACK bosses, not here
  thru_circ(39.00,17.00,6.2);
  thru_circ(54.00,17.00,6.2);
  thru_circ(69.00,17.00,6.2);
  thru_circ(84.00,17.00,6.2);
  thru_circ(99.00,17.00,6.2);
  thru_circ(114.00,17.00,6.2);
  thru_circ(129.00,17.00,6.2);
  thru_circ(144.00,17.00,6.2);
  thru_circ(172.00,17.00,6.2);
  thru_circ(187.00,17.00,6.2);
  thru_circ(202.00,17.00,6.2);
  thru_circ(217.00,17.00,6.2);
  thru_rrect(8.00,5.50,9.33,6.77,3.3);
  thru_rrect(8.00,126.50,9.33,6.77,3.3);
  thru_rrect(246.00,5.50,9.33,6.77,3.3);
  thru_rrect(246.00,126.50,9.33,6.77,3.3);
} }
difference(){ union(){ cube([FACE_W,FACE_H,TH]); bosses(); } cuts(); screw_blind(); }

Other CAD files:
hardware/faceplate/faceplate_paint.scad

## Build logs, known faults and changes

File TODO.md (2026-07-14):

# TODO

Open items for the IMSPI 8080 project.

## Mechanical — grab the final 3U 3D design
- [ ] Pull the **final 3-D design for the 10" rack 3U enclosure/panel** from the
      **jetson-marker-turret** project (that's where the enclosure CAD lives — this panel
      is its front face, housing an RPi 5 + Jetson Orin AGX 64GB).
- [ ] Reconcile it against [`hardware/design-spec.md`](hardware/design-spec.md): 214 × 70 mm
      board, 3U face, ~3–5 mm standoffs. Verify against the real model, not the estimated
      fit-check dimensions.
- [ ] Finalize: bezel LED windows (align to the LED grid), **standoff height** (must match
      the real toggle bushing length — can't fix after fab), and the **separate toggle
      bracket** wired to J3/J4.

## Rev1 bring-up (when the board arrives, ~mid/late July 2026)
- [ ] Flash firmware: hold **BOOTSEL (SW1)**, plug USB into J1, drag the `.uf2` (build from
      [`firmware/`](firmware/), Pico SDK).
- [ ] Bring-up with [`host/`](host/) Python driver + `examples/lamp_test.py` over `/dev/ttyACM0`.

## Future — 19" faithful build
- [ ] Build a full-size **19" 4U** fully-faithful IMSAI 8080 (~450 × 178 mm ≈ real IMSAI,
      ~40 LEDs / 16-bit switch set). Reuse this project's architecture, SKiDL generator,
      placement/routing scripts, and firmware at the larger size.

### Rev1 notes to carry into rev2
- **Trim board to 204 × 60 mm (−10 mm each axis) — structural, not cosmetic.** The carrier-
  plate side flanges, front L-gussets, and rail-mount hardware all run down the side margins;
  the current full-width 214 mm PCB (mounting holes only 7 mm from each edge) leaves no room
  for them. Pulling the board in ~5 mm/side opens the clearance channels the rigidity scheme
  needs; trimming height frees the band below the LEDs for the front flange + toggle bracket.
  This is a **re-layout, not an outline crop**: the LED grid (currently x = 15–205 mm) must
  pull inward and the edge holes/connectors move with it. See the carrier-plate rigidity plan.
- Fine-pitch parts need **0.15 mm track / 0.13 mm clearance** rules (0.25/0.2 couldn't
  escape the RP2040 QFN-56 0.4 mm pitch).
- Ground is routed as **traces** (no solid plane on this dense 2-layer board).
- Flash (U2) ended up far from U1 — place it tight to the RP2040 next time.

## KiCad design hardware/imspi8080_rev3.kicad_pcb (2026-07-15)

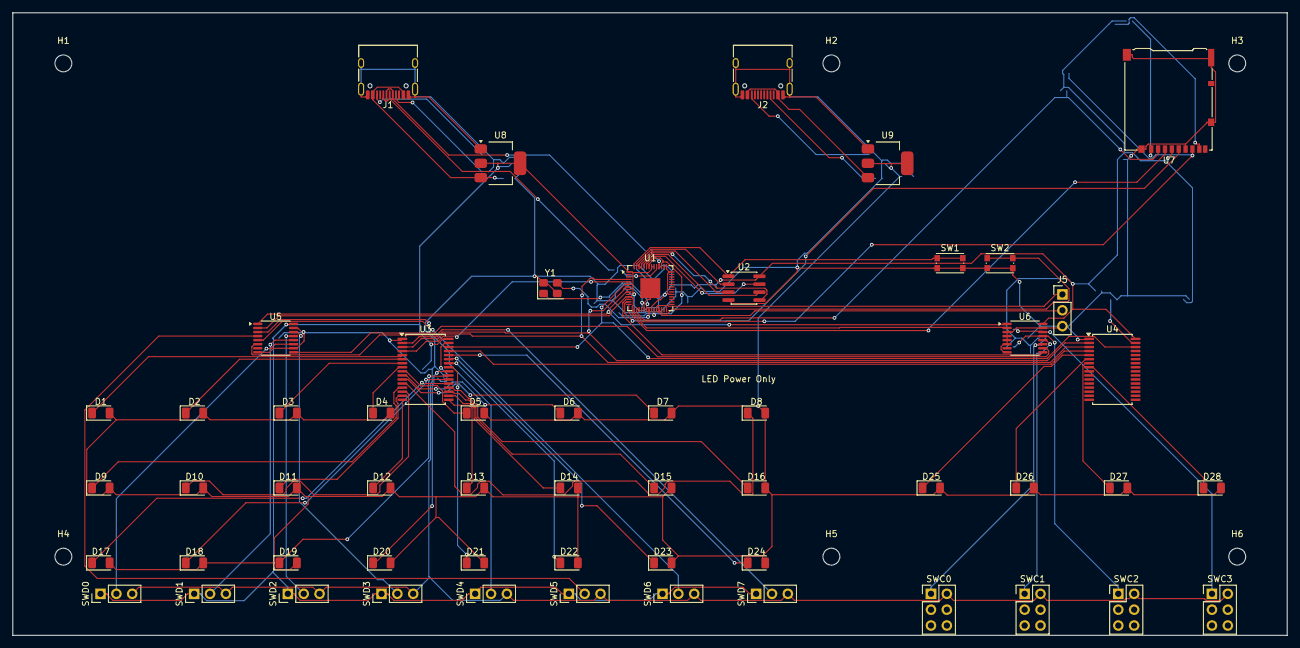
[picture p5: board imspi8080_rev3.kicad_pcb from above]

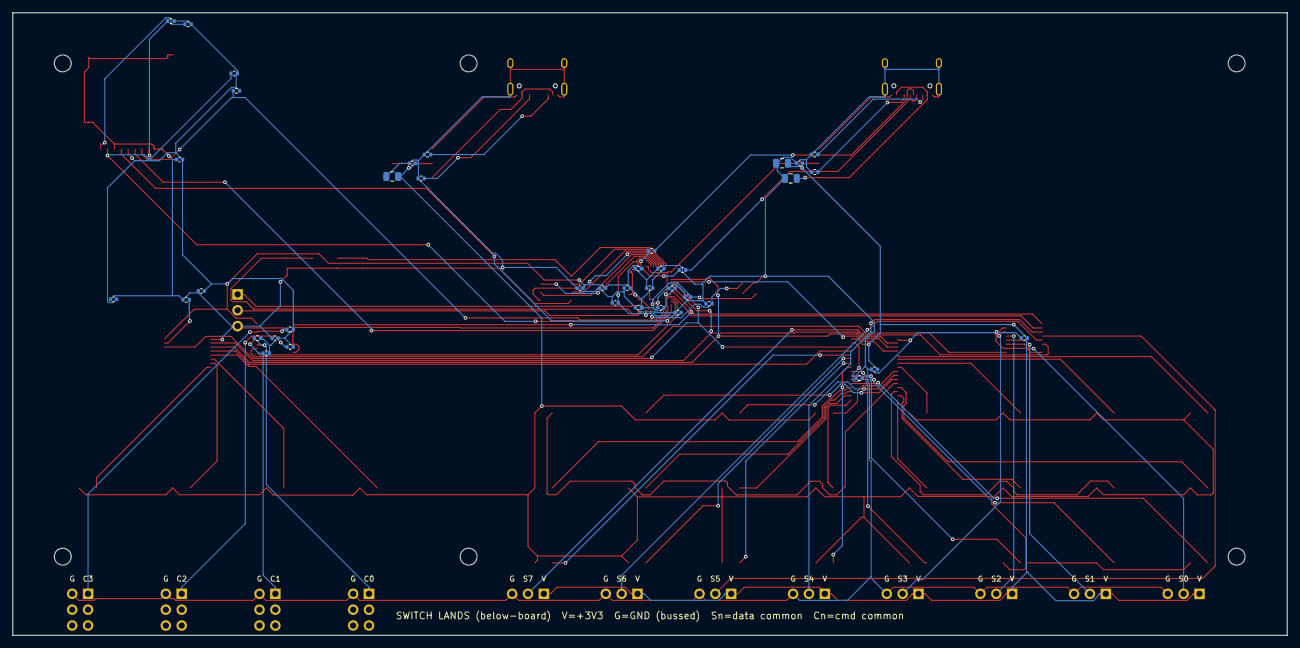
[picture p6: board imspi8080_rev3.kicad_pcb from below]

Board: 2 copper layers, 204.1 x 99.7 mm, 101 parts (40 on the bottom side), 82 nets.

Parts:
C1, C2, C3, C4, C5, C6, C7, C8, C9, C10, C11, C12, C13, C14, C15: 100nF; C_0402_1005Metric
C16, C17, C18, C19: 1uF; C_0402_1005Metric
C20, C21, C22: 10uF; C_0805_2012Metric
C23, C24: 15pF; C_0402_1005Metric
D1, D2, D3, D4, D5, D6, D7, D8, D9, D10, D11, D12, D13, D14, D15, D16, D17, D18, D19, D20, D21, D22, D23, D24, D25, D26, D27, D28: LED; LED_1206_3216Metric
H1, H2, H3, H4, H5, H6: MountingHole; MountingHole_2.7mm_M2.5
J1, J2: USB_C_Receptacle_USB2.0_16P; USB_C_Receptacle_HRO_TYPE-C-31-M-12
J5: Conn_01x03_Pin; PinHeader_1x03_P2.54mm_Vertical
R1, R2, R3, R4: 5.1k; R_0402_1005Metric
R5, R6: 27; R_0402_1005Metric
R7, R8: 2.4k; R_0402_1005Metric
R9, R10, R11, R12, R13, R14, R15, R16: 10k; R_0402_1005Metric
SW1, SW2: SW_Push; SW_Push_1P1T_NO_CK_KMR2
SWC0, SWC1, SWC2, SWC3: SW_LAND; PinHeader_2x03_P2.54mm_Vertical
SWD0, SWD1, SWD2, SWD3, SWD4, SWD5, SWD6, SWD7: SW_LAND; PinHeader_1x03_P2.54mm_Vertical
U1: RP2040; QFN-56-1EP_7x7mm_P0.4mm_EP3.2x3.2mm
U2: W25Q128JVS; SOIC-8_3.9x4.9mm_P1.27mm
U3, U4: TLC5947DAP; Texas_DAD0032A_HTSSOP-32_6.1x11mm_P0.65mm_TopEP3.71x3.81mm
U5, U6: 74HC165; TSSOP-16_4.4x5mm_P0.65mm
U7: Micro_SD_Card; microSD_HC_Hirose_DM3AT-SF-PEJM5
U8, U9: AMS1117-3.3; SOT-223-3_TabPin2
Y1: 12MHz; Crystal_SMD_3225-4Pin_3.2x2.5mm

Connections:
+3V3: C1.1, C2.1, C3.1, C4.1, C5.1, C6.1, C7.1, C8.1, C9.1, C10.1, C11.1, C12.1, C13.1, C15.1, C18.1, C19.1, C20.1, R9.1, R10.1, R11.1, R12.1, R13.1, R14.1, R15.1, R16.1, SWD0.1, SWD1.1, SWD2.1, SWD3.1, SWD4.1, SWD5.1, SWD6.1, SWD7.1, U1.1, U1.10, U1.22, U1.33, U1.42, U1.43, U1.44, U1.48, U1.49, U2.8, U3.32, U4.32, U5.16, U6.16, U7.4, U8.2
+3V3_LED: C14.1, C21.1, D1.2, D2.2, D3.2, D4.2, D5.2, D6.2, D7.2, D8.2, D9.2, D10.2, D11.2, D12.2, D13.2, D14.2, D15.2, D16.2, D17.2, D18.2, D19.2, D20.2, D21.2, D22.2, D23.2, D24.2, D25.2, D26.2, D27.2, D28.2, U9.2
CMD0: R13.2, SWC0.1, U6.11
CMD1: R14.2, SWC1.1, U6.12
CMD2: R15.2, SWC2.1, U6.13
CMD3: R16.2, SWC3.1, U6.14
GND: C1.2, C2.2, C3.2, C4.2, C5.2, C6.2, C7.2, C8.2, C9.2, C10.2, C11.2, C12.2, C13.2, C14.2, C15.2, C16.2, C17.2, C18.2, C19.2, C20.2, C21.2, C22.2, C23.2, C24.2, J1.A1, J1.A12, J1.B1, J1.B12, J1.SH, J2.A1, J2.A12, J2.B1, J2.B12, J2.SH, J5.3, R1.2, R2.2, R3.2, R4.2, R7.2, R8.2, SW1.2, SW2.2, SWC0.2, SWC1.2, SWC2.2, SWC3.2, SWD0.3, SWD1.3, SWD2.3, SWD3.3, SWD4.3, SWD5.3, SWD6.3, SWD7.3, U1.19, U1.57, U2.4, U3.1, U4.1, U5.8, U5.10, U5.15, U6.3, U6.4, U6.5, U6.6, U6.8, U6.15, U7.6, U7.SH, U8.1, U9.1, Y1.2, Y1.4
HC_CHAIN: U5.9, U6.10
HC_CLK: U1.11, U5.2, U6.2
HC_PLOAD: U1.9, U5.1, U6.1
HC_QH: U1.12, U6.9
unnamed: J5.1, U1.24
unnamed: J5.2, U1.25
unnamed: J1.A5, R1.1
unnamed: J1.B5, R2.1
unnamed: J2.A5, R3.1
unnamed: J2.B5, R4.1
unnamed: R5.2, U1.47
unnamed: R6.2, U1.46
unnamed: R7.1, U3.31
unnamed: R8.1, U4.31
unnamed: D1.1, U3.5
unnamed: D2.1, U3.6
unnamed: D3.1, U3.7
unnamed: D4.1, U3.8
unnamed: D5.1, U3.9
unnamed: D6.1, U3.10
unnamed: D7.1, U3.11
unnamed: D8.1, U3.12
unnamed: D9.1, U3.13
unnamed: D10.1, U3.14
unnamed: D11.1, U3.15
unnamed: D12.1, U3.16
unnamed: D13.1, U3.17
unnamed: D14.1, U3.18
unnamed: D15.1, U3.19
unnamed: D16.1, U3.20
unnamed: D17.1, U3.21
unnamed: D18.1, U3.22
unnamed: D19.1, U3.23
unnamed: D20.1, U3.24
unnamed: D21.1, U3.25
unnamed: D22.1, U3.26
unnamed: D23.1, U3.27
unnamed: D24.1, U3.28
unnamed: D25.1, U4.5
unnamed: D26.1, U4.6
unnamed: D27.1, U4.7
unnamed: D28.1, U4.8
unnamed: R11.2, U7.8
unnamed: R12.2, U7.1
QSPI_SCLK: U1.52, U2.6
QSPI_SD0: U1.53, U2.5
QSPI_SD1: U1.55, U2.2
QSPI_SD2: U1.54, U2.3
QSPI_SD3: U1.51, U2.7
QSPI_SS: SW1.1, U1.56, U2.1
RUN: SW2.1, U1.26
SD_CS: R9.2, U1.16, U7.2
SD_MISO: R10.2, U1.15, U7.7
SD_MOSI: U1.14, U7.3
SD_SCK: U1.13, U7.5
SW0: SWD0.2, U5.11
SW1: SWD1.2, U5.12
SW2: SWD2.2, U5.13
SW3: SWD3.2, U5.14
SW4: SWD4.2, U5.3
SW5: SWD5.2, U5.4
SW6: SWD6.2, U5.5
SW7: SWD7.2, U5.6
TLC_BLANK: U1.7, U3.2, U4.2
TLC_CHAIN: U3.29, U4.4
TLC_SCLK: U1.4, U3.3, U4.3
TLC_SIN: U1.5, U3.4
TLC_XLAT: U1.6, U3.30, U4.30
USB_DM_CONN: J1.A7, J1.B7, R6.1
USB_DP_CONN: J1.A6, J1.B6, R5.1
VBUS_LED: J2.A4, J2.A9, J2.B4, J2.B9, U9.3
VBUS_LOGIC: C22.1, J1.A4, J1.A9, J1.B4, J1.B9, U8.3
VCORE: C16.1, C17.1, U1.23, U1.45, U1.50
XIN: C23.1, U1.20, Y1.1
XOUT: C24.1, U1.21, Y1.3

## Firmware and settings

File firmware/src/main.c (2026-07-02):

#include "config.h"
#include "crc8.h"
#include "tlc5947.h"
#include "hc165.h"
#include "protocol.h"

#include "pico/stdlib.h"
#include <stdio.h>
#include <string.h>

// --- lamp state ------------------------------------------------------------
static led_state_t g_led;        // last commanded lamp state
static bool g_lamp_test = false; // lamp-test override active

// Map a byte register onto 8 consecutive TLC channels, MSB (bit7) -> base+0.
// A set data bit lights that lamp at the current brightness.
static void map_byte(uint8_t base, uint8_t value, uint16_t on_gs) {
    for (int i = 0; i < 8; i++) {
        int bit = (value >> (7 - i)) & 1;
        tlc_set(base + i, bit ? on_gs : 0);
    }
}

static void render(void) {
    if (g_lamp_test) {
        tlc_set_all(TLC_GS_MAX);
        tlc_show();
        return;
    }
    // brightness 0..255 -> 12-bit grayscale
    uint16_t on = (uint16_t)((g_led.bright << 4) | (g_led.bright >> 4));
    map_byte(CH_ADDR_HI_BASE, g_led.addr_hi, on);
    map_byte(CH_ADDR_LO_BASE, g_led.addr_lo, on);
    map_byte(CH_DATA_BASE,    g_led.data,    on);
    for (int i = 0; i < 4; i++) {
        int bit = (g_led.status >> i) & 1;
        tlc_set(CH_STATUS_BASE + i, bit ? on : 0);
    }
    tlc_show();
}

// --- protocol handlers -----------------------------------------------------
static void on_led(const led_state_t *s)      { g_led = *s; render(); }
static void on_lamp_test(bool on)             { g_lamp_test = on; render(); }
static void on_brightness(uint8_t level)      { g_led.bright = level; render(); }

static void send_frame(const uint8_t *f, int n) {
    for (int i = 0; i < n; i++) putchar_raw(f[i]);
}

static void on_ping(void) {
    uint8_t f[5];
    int n = proto_build_version(f);
    send_frame(f, n);
}

// --- switch debounce + edge latch ------------------------------------------
static uint16_t sw_stable;        // debounced switch word
static uint16_t sw_candidate;     // last raw sample
static int      sw_count;         // consecutive matching samples
static uint8_t  cmd_prev;         // previous command-switch nibble
static uint8_t  events_latched;   // rising edges since last report

static void sample_switches(void) {
    uint16_t raw = hc165_read();
    if (raw == sw_candidate) {
        if (sw_count < DEBOUNCE_STABLE) sw_count++;
    } else {
        sw_candidate = raw;
        sw_count = 0;
    }
    if (sw_count >= DEBOUNCE_STABLE && raw != sw_stable) {
        sw_stable = raw;
        uint8_t cmd = (uint8_t)((sw_stable >> SW_CMD_BASE) & 0x0F);
        uint8_t rising = (uint8_t)(cmd & ~cmd_prev);   // 0->1 transitions
        events_latched |= rising;
        cmd_prev = cmd;
    }
}

static void send_switch_report(void) {
    uint8_t sw_data = (uint8_t)((sw_stable >> SW_DATA_BASE) & 0xFF);
    uint8_t sw_cmd  = (uint8_t)((sw_stable >> SW_CMD_BASE) & 0x0F);
    uint8_t f[6];
    int n = proto_build_switch(f, sw_data, sw_cmd, events_latched);
    send_frame(f, n);
    events_latched = 0;   // consumed
}

int main(void) {
    stdio_init_all();
    stdio_set_translate_crlf(&stdio_usb, false);   // binary-clean CDC

    tlc_init();
    hc165_init();

    proto_handlers_t h = {
        .on_led = on_led,
        .on_lamp_test = on_lamp_test,
        .on_brightness = on_brightness,
        .on_ping = on_ping,
    };
    proto_init(&h);

    g_led.bright = 255;
    render();

    absolute_time_t next_debounce = get_absolute_time();
    absolute_time_t next_heartbeat = get_absolute_time();
    uint16_t last_reported = 0xFFFF;

    for (;;) {
        // Drain incoming host bytes without blocking.
        int c;
        while ((c = getchar_timeout_us(0)) != PICO_ERROR_TIMEOUT) {
            proto_feed((uint8_t)c);
        }

        if (absolute_time_diff_us(get_absolute_time(), next_debounce) <= 0) {
            sample_switches();
            next_debounce = delayed_by_ms(get_absolute_time(), DEBOUNCE_MS);

            bool changed = (sw_stable != last_reported) || (events_latched != 0);
            if (changed) {
                send_switch_report();
                last_reported = sw_stable;
                next_heartbeat = delayed_by_ms(get_absolute_time(), HEARTBEAT_MS);
            }
        }

        if (absolute_time_diff_us(get_absolute_time(), next_heartbeat) <= 0) {
            send_switch_report();
            last_reported = sw_stable;
            next_heartbeat = delayed_by_ms(get_absolute_time(), HEARTBEAT_MS);
        }
    }
}

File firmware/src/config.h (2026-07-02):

#ifndef IMSPI_CONFIG_H
#define IMSPI_CONFIG_H

// ---------------------------------------------------------------------------
// IMSPI 8080 panel firmware configuration
//
// Pin numbers are RP2040 GPIO numbers (Pico). Adjust to your board.
// ---------------------------------------------------------------------------

// --- TLC5947 LED driver chain ----------------------------------------------
#define TLC_COUNT        2          // number of daisy-chained TLC5947s
#define TLC_CHANNELS     24         // channels per device
#define TLC_TOTAL_CH     (TLC_COUNT * TLC_CHANNELS)   // 48
#define TLC_GS_MAX       4095       // 12-bit grayscale

#define PIN_TLC_SIN      3          // serial data in  (SPI TX / bit-bang)
#define PIN_TLC_SCLK     2          // serial clock    (SPI SCK)
#define PIN_TLC_XLAT     4          // latch pulse
#define PIN_TLC_BLANK    5          // blank / GS counter reset (active high)
#define PIN_TLC_GSCLK    6          // grayscale PWM reference clock
#define TLC_GSCLK_HZ     1000000    // grayscale clock frequency

// Set to 1 if your physical cascade wiring clocks device 0 first instead of
// the last device first (flip if the wrong chip lights up).
#define TLC_REVERSE_DEVICE_ORDER 0

// --- 74HC165 switch chain --------------------------------------------------
#define HC165_COUNT      2          // daisy-chained 74HC165s -> 16 inputs
#define HC165_BITS       (HC165_COUNT * 8)            // 16

#define PIN_HC_PLOAD     10         // SH/LD  (active low parallel load)
#define PIN_HC_CLK       11         // CLK
#define PIN_HC_DATA      12         // QH from the last device in the chain

// Set to 1 to reverse bit order if switches map backwards.
#define HC165_REVERSE_BITS 0

// --- Lamp channel map (index into the TLC grayscale buffer) ----------------
// Left block rows + right status row. bit i of each register -> a channel.
#define CH_ADDR_HI_BASE  0          // A15..A8  -> ch 0..7   (bit7=A15 -> ch0)
#define CH_ADDR_LO_BASE  8          // A7..A0   -> ch 8..15
#define CH_DATA_BASE     16         // D7..D0   -> ch 16..23
#define CH_STATUS_BASE   24         // status0..3 -> ch 24..27

// --- Switch bit map (index into the 16-bit HC165 word) ---------------------
#define SW_DATA_BASE     0          // data toggles 0..7 -> bits 0..7
#define SW_CMD_BASE      8          // command switches 0..3 -> bits 8..11
#define SW_CMD_COUNT     4

// --- Timing ----------------------------------------------------------------
#define DEBOUNCE_MS      5          // switch sample interval
#define DEBOUNCE_STABLE  3          // stable samples required to accept a change
#define HEARTBEAT_MS     250        // periodic switch report even if unchanged

// --- Protocol --------------------------------------------------------------
#define SOF_HOST_TO_PANEL 0xA5
#define SOF_PANEL_TO_HOST 0x5A

#define CMD_LED           0x01      // 8-byte LED update
#define CMD_LAMP_TEST     0x02      // 4-byte lamp test
#define CMD_BRIGHTNESS    0x03      // 4-byte set brightness
#define CMD_PING          0x7F      // 3-byte ping

#define RSP_SWITCH        0x81      // 6-byte switch report
#define RSP_VERSION       0xC0      // 5-byte version

#define VERSION_MAJOR     0
#define VERSION_MINOR     1

#endif // IMSPI_CONFIG_H

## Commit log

2026-07-02 initial load
    [bom.csv]
2026-07-07 feat: complete IMSPI 8080 hardware design and JLCPCB rev1 fab package
    Board is fully routed (85 parts, 0 unrouted), DRC-clean, and ordered.
    - imspi8080_skidl.py: fix + complete the schematic-as-code — correct
    symbol/pin names for KiCad 10, add the full RP2040 support circuit
    (QSPI flash, 12MHz crystal, USB series Rs, BOOTSEL/RUN), dual USB-C,
    microSD, and JST switch-bank headers
    - imspi8080.kicad_pro / .kicad_pcb / .net: KiCad 10 project + routed
    2-layer board (214x70mm). Decoupling caps on the back side; fine-pitch
    design rules (0.15mm track / 0.13mm clearance) to escape the RP2040 QFN
    - place_holes.py / place_passives.py: board-relative placement helpers
    (M2.5 mounting holes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
    [imspi8080-bom.csv, imspi8080.kicad_pcb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]
2026-07-07 docs: add TODO.md with project open items
    - Mechanical: grab the final 10" 3U 3D enclosure design from the
    jetson-marker-turret project; reconcile standoffs + toggle bracket
    - Rev1 bring-up steps (firmware flash + host lamp test on arrival)
    - Future 19" faithful IMSAI build + rev2 layout notes
    Claude-Session: https://claude.ai/code/session_01D2uBTm2rbJxDrjkQXCydg1
2026-07-14 feat: rev2 (204x60) + rev3 (3-band, on-board switches) revisions + 3D faceplate
    Rev2: trimmed 214x70 -> 204x60 to open carrier-plate side-flange clearance;
    fully placed + routed, fab files in hardware/jlcpcb-rev2/, notes in REV2-NOTES.md.
    Rev3: taller 204x95, 3-band architecture (connectors top / digital / LEDs bottom),
    J3/J4 replaced by bare solder-pad rows for fascia-mounted MTS-123/223 switches.
    Fully routed, 0 unconnected (extra room cleared the RP2040 QFN escape). Built via
    rev3_build.py by transforming the rev2 board.
    Faceplate: parametric OpenSCAD 3D panel (hardware/faceplate/) with ink-recess
    labels (white brand / gold legend), IMSAI blue open-bottom frame pulled inboard,
    mounting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
    [faceplate_3d.scad, faceplate_paint.scad, imspi8080-rev2-bom.csv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]
2026-07-14 chore: archive rev1/rev2 into hardware/OLD/, focus hardware/ on rev3
    Moved all rev1 (ordered) and rev2 boards, fab files, routing, and placement
    scripts into hardware/OLD/. hardware/ now holds only rev3 + shared source
    (imspi8080_skidl.py, design-spec.md, bom.csv) + the faceplate. Updated
    rev3_build.py source path to OLD/imspi8080_rev2.kicad_pcb.
    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
    [imspi8080-B_Cu.gbl, imspi8080-B_Mask.gbs, imspi8080-B_Paste.gbp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]
2026-07-15 feat(rev3): void-switch design — on-board fascia switches through PCB voids
    Reworked rev3 into a signal-flow placement (RP2040 center, one TLC per LED bank,
    '165s toward their switch pads) on a 204x112 board. J3/J4 replaced by 12 per-switch
    landing-pad clusters (data 1x03, command 2x03) over body voids: fascia-mounted
    MTS-123/223 switches drop their bodies through the cutouts (board stays close ->
    crisp LEDs), pins jumper to the pads. Back-silk labels every pad (Sn/Cn/V/G) with a
    legend; 3V3/GND rails bussed. Fully routed, 0 unconnected (10 track-to-void
    clearances remain for the KiCad finish). Build: rev3_place2.py -> rev3_voids.py.
    Faceplate updated to 204x112: toggle holes over the voi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
    [faceplate_3d.scad, faceplate_paint.scad, imspi8080_rev3.kicad_pcb]
2026-07-15 feat(rev3): landing-pad switch design + fab package; archive void detour
    Replaced the switch-through-void design (un-solderable: pins ended up behind the
    switch body with no reachable pad) with a solderable landing-pad scheme: switches
    mount on the fascia just below the board's bottom edge and jumper straight up to a
    labeled pad cluster each (SWD0-7 data 1x3, SWC0-3 command 2x3; back-silk V/Sn/G,
    Cn/G). No voids, no connectors, no cables. Board 204x99.7, fully routed, DRC-clean
    (0 unconnected, 0 errors). Build chain: rev3_place2.py -> rev3_pads.py.
    Added jlcpcb-rev3/ upload package: gerbers.zip (copper/mask/silk/paste + PTH/NPTH
    drill), CPL (83 SMT parts), BoM (electronics only; switch land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
    [faceplate_3d.scad, faceplate_paint.scad, imspi8080-bom.csv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]
2026-10-10 feat(rev4): fully routed 204x60 board + fab package
    - place_rev4.py: center-channel placement (R6 south of U1 so USB_DM/pin 46
    escapes under the body; U2 3.15mm closer so the QSPI herringbone fits)
    - add_n7/n8_guide.py: B.Cu birth-guides for the two boxed USB pads
    - Freerouting 1.9.0 flow: export_dsn -> patch_dsn (150/127 rules) -> import_ses
    - post_route.py GND pour + fixup_final.py (edge vias, VBUS feeds, LED rail)
    - KiCad DRC: 0 errors; J1-A6 intentionally NC (plug parallels A6/B6)
    - fab-rev4/: gerbers (separated PTH/NPTH drill), BOM, CPL, KiCad source,
    imspi8080-rev4-fab.zip (JLCPCB/PCBWay-ready)
    - archive rev3 files under hardware/OLD/
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2026-10-10 feat(rev5): on-board 12-toggle IMSAI switch array, 4-layer, fab package
    - place_rev5.py: rev3's proven 204x112 2U placement + rev4 lessons
    (R5/R6 south of U1, N$7/N$8 B.Cu birth-guides)
    - All 12 toggles on-board (8 latching data + 4 momentary command, SPDT,
    15mm pitch under LED rows, bushings through board voids) - the
    integrated-switch build: no J3/J4 bracket harness
    - 2-layer attempted first (81/82), promoted to 4-layer per approved
    fallback; XIN/XOUT/TLC_SCLK escapes hand-finished
    - DRC: 0 errors; 3 documented assembly items (HC_QH wire, TLC_SCLK
    0-ohm bridge, optional GND stitch via); J1-A6 intentionally NC
    - fab-rev5/: 4-layer gerbers (split drill), BOM (+12 toggles, xlsx),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
2026-10-10 fix(rev5): include schematic in fab package (rev4 sch = same netlist)
2026-10-10 feat(case): recover 3U rack case from turret history, re-align to rev5 PCB
    Recover turret-gimbal/cad/scad/rack_shelf.scad @ jetson-marker-turret f57c7c1^
    (stripped from the turret working tree 2026-07-14 in the move to this repo)
    as hardware/case/rack_case.scad: fascia + tray + side gussets + blue frame.
    Re-derive every board-facing feature from the measured imspi8080_rev5.kicad_pcb
    (204.1x112.1): LED windows (cols 14.13+15k/147.13+15k, rows 64.13/76.13/88.13),
    12 toggle holes at the void centers (y=103.06), 6 PCB bosses at
    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
2026-10-10 chore(consolidate): single source of truth for panel/case CAD — this repo owns it
    Recovered the last panel files that only existed in jetson-marker-turret git
    history (@f57c7c1^): imsai_paddle_cap.scad (12 toggle paddle caps, now
    hardware/case/) and docs/Imsai_Panel_HMI.md (legend/HMI spec both fascia
    generators consume). The turret's tracked tree was already clean of panel
    files; its untracked ten-inch-rack-specs.md is byte-identical to the copy in
    hardware/faceplate/ and stays there as a rack reference.
    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
2026-10-10 docs(fab-rev5): correct TLC_SCLK bridge endpoints after copper trace
    Direct copper trace of the committed rev5 board (2026-10-10): TLC_SCLK is
    two islands - {U1-4, 2 trks, via (124.32,94.60)} and the {U3-3 -> U4-3}
    chain; the earlier README coordinates described a pre-fixup geometry. Bridge
    is a ~10 mm wire (0-ohm 0402 cannot span 8.2 mm). HC_QH confirmed fully
    open (zero copper); GND fully connected incl. R7-2/C18-2 via pad-entry
    tracks - the documented island pair is pad-less pour slivers (cosmetic).
2026-10-10 test(hardware): check_opens.py - open-net checker kicad-cli drc can't provide
    kicad-cli pcb drc (KiCad 10.0) reports zero unconnected_items violations on
    this board despite two real opens (HC_QH, TLC_SCLK) - verified not DRC
    exclusions, not severity gating, not the prl ratsnest flag. Root cause looks
    like a headless ratsnest/reporting gap; no board setting re-enables it.
    So the pre-fab gate is now a standalone flood-fill checker: layer-aware
    copper-overlap union-find over pads (rotated rects), tracks and vias
    (annulus), incl. GND-pour membership for items on the zone's layer. Fails
    (exit 1) on any multi-island net with membership; documented assembly opens
    + rev4's intentional J1-A6 NC pad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
2026-10-10 fab(rev5): refresh JLCPCB package - add xlsx BOM, current README
    Regenerate imspi8080-rev5-fab.zip: gerbers unchanged (board untouched since
    Oct 9), README.txt refreshed (corrected TLC_SCLK bridge endpoints + the
    check_opens.py pre-fab note), and add the xlsx BOM alongside the csv (same
    treatment as the rev4 package). CPL stays in JLCPCB columns.
2026-10-10 fab(rev5): MacroFab package for cost comparison
    Per-vendor directory mirroring the pcb-vendors convention: hardware/fab-rev5/
    macrofab/ contains MacroFab's upload set -
    imspi8080_rev5-odb.zip ODB++ (preferred ingest, KiCad 10 export)
    imspi8080-rev5-gerbers.zip RS-274X + Excellon PTH/NPTH fallback
    imspi8080-rev5-bom-macrofab.csv/.xlsx Designator/Description/Mfr/MPN/
    Qty/Footprint/Notes (mfr filled where
    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
2026-10-10 fab(rev5): split JLCPCB upload dirs - gerbers-only and CPL-only
    JLCPCB's flow wants the fab data and pick-and-place as separate uploads:
    jlcpcb-gerbers/ 14 files - all copper/mask/paste/silk + Edge_Cuts +
    Excellon PTH/NPTH + gbrjob (nothing else)
    jlcpcb-cpl/ imspi8080-rev5-cpl.csv only (JLCPCB columns, mm)
2026-10-10 fab(rev5): zip of the JLCPCB gerber upload set
    imspi8080-rev5-gerbers-jlcpcb.zip = jlcpcb-gerbers/ contents at zip root
    (14 files). Upload this at JLCPCB's board step.
2026-10-10 fab(rev5): explode BOM to one row per designator (JLCPCB matcher fix)
    JLCPCB failed the upload: BOM designators were ';'-joined strings
    ('U5;U6', 'D1;D2;...') which don't match the per-designator CPL rows -
    'U5,U6,...,U3,U4 don't exist in the BOM' + every ';' string 'doesn't exist
    in the CPL'.
    Now: BOM has exactly the 82 CPL designators, one per row (csv + xlsx rebuilt;
    BOM set == CPL set, verified). User-fitted parts are intentionally absent
    from BOTH: the 12 board-mounted toggles (MTS-102/103-M), spare pull-ups
    R17/R18, and the optional J5 debug header. Same 82-row BOM regenerated for
    the macrofab/ package. README documents the 1:1 match and the user-fitted
    list. Zips rebuilt.
2026-10-10 fab(rev5): fab-assembled through-hole toggles in BOM+CPL+XYRS
    User wants the fab house to assemble the 12 toggles. Added to BOTH vendor
    packages (BOM<->CPL / BOM<->XYRS verified 1:1 at 94 rows each):
    SWD0-7 MTS-102 latching @ void centers (49.325..154.325, 156.825)
    SWC0-3 MTS-103-M momentary @ (182.325..227.325, 156.825)
    All: Top side (pads are F.Cu), rotation 0 (terminals toward LED rows),
    placement = bushing center = board-void center (measured Edge.Cuts).
    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
2026-10-10 fab(rev5): add J5 debug header to assembly data (both vendors)
    J5 1x3 2.54mm TH header now in BOM+CPL (JLCPCB) and BOM+XYRS (MacroFab):
    position (203.375, 98.875) rot 0 Top from the board footprint (pads
    N$1/N$2/GND). Verified 1:1 at 95 rows per vendor. Only R17/R18 spares
    remain user-fitted. Zips + README refreshed.
2026-10-10 fab(rev5): LCSC part numbers in BOM for JLCPCB auto-match
    Adds 'LCSC Part #' column (22 rows) so the JLCPCB matcher resolves the
    parts it couldn't find: RP2040 C2761095, flash C97521, TLC5947 C1554203,
    165 C43420, USB-C C165948, crystal C9002, microSD C91145 (verify package),
    MTS-102=C1788492, MT-0-103 C1788493 (VERIFY momentary in datasheet; note
    says supply MTS-103-M yourself if latching-only). SW1/SW2/J5 annotated as
    tool-picked. Passives/LEDs stay blank (JLCPCB auto-matches them).
2026-10-10 rev6 (wip): RP2350A netlist + schematic + pre-route board
    Netlist surgery: U1 -> RP2350A (QFN-60-1EP 7x7 thermal-vias) with full pin
    remap per REV6-PLAN.md; new L1 2.2uH (Bourns SRU5016 fp) wiring VREG_LX
    (U1-48) to VREG_FB=VCORE; +3V3 also feeds VREG_AVDD/VIN + ADC_AVDD +
    USB_OTP_VDD + QSPI_IOVDD; DVDD pins 6/23/39 on VCORE. Schematic regen
    (gen_schematic.py) round-trip verified: every source net matches the export.
    Board copy imspi8080_rev6.kicad_pcb: U1 footprint swapped at same pos/orient
    (7x7 body), pads remapped, D1-D28 shifted -0.075mm to switch-pad columns,
    L1 placed (138.713,86.854) r180, MCU-cluster + LED nets ripped (1166 trks /
    105 vias). min through-drill relaxed 0.25->0.20mm f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
2026-10-10 firmware: RP2350 (pico2) port + fix stale HC165 pin map
    - HC_PLOAD/CLK/DATA: 10/11/12 -> 7/8/9 (matches the routed board; the old
    values were wrong even for rev5 hardware - discovered during rev6 mapping)
    - Add SD card SPI1 pin defines (GPIO10-13)
    - Drop PIN_TLC_GSCLK + PWM init: TLC5947 has an internal grayscale
    oscillator; the net was never wired on rev5/rev6 (dead code)
    - CMakeLists: PICO_BOARD=pico2, drop hardware_pwm
    - No RP2040-only APIs anywhere else (stdio/gpio/time only) - no changes
    needed in main/protocol/hc165/crc8
    Build NOT verified here yet - no Pico SDK on this machine (installing).
2026-10-10 firmware: rev6 RP2350 build verified + README build notes
    imspi8080.uf2 built against pico-sdk 2.1.1 + arm-gnu 13.2: 52KB, UF2
    family 0xe48bff56 (RP2350 confirmed). HC165 pins now 7/8/9 (matches the
    routed rev6 board and rev5 hardware). Toolchain lives in ~/opt (no sudo);
    SDK in ~/pico.
2026-10-10 rev6 (wip): post-route baseline (SES import + GND pour, one zone)
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2026-10-10 rev6: complete — fully routed RP2350A board, fab package, clean checks
    Board: DRC 110 (all cosmetic: 80 back-silk text, 24 silk overlap,
    6 stub warnings), 0 errors. check_opens.py: every net a single copper
    island — the two rev5 assembly wires (HC_QH, TLC_SCLK) are routed, the
    allow-list is empty for rev6. Fixed along the way: freerouting GND
    skip root-caused (KiCad DSN emits the GND zone as a Specctra plane;
    fix = no zones before export_dsn), duplicate via + zero-length stubs
    cleaned, checker now reads pads' full copper layer set (GetLayer lies
    for multi-layer pads).
    Fab package fab-rev6/: gerbers (14), drill PTH/NPTH, gbrjob, BOM
    csv+xlsx (96 rows: U1=RP2350A C42411118 in stock at JLC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
2026-10-10 fab(rev6): guide-compliant crystal spec (10pF CL) + L1 orientation note
    JLCPCB flagged crystal + polarised inductor vs the RP2350 design guide:
    - Y1 = 12MHz 3225 CL=10pF (ABM8-272-T3 class) w/ the 15pF caps - rev5's
    20pF-load crystal would run off-tune with 15pF caps. BOM-only change.
    - L1: RP2350 SMPS inductor is polarity-sensitive (guide Figure); pick a
    marked part, order remark 'dot toward U1'. Board uses no ADC -> low
    practical risk, but documented for the assembler.
2026-10-10 fab(rev6): L1 = SMNR4020-2.2UH C135262 (4040, 3.4A/3.4A, 46mOhm)
    Selected in JLCPCB picker after stock check; 4x4mm lands inside the
    5.2mm SRU5016-pattern pads. Crystal line still pending the user's pick.
2026-10-10 fab(rev6): Y1 = ABM8-272-T3 C20625731 - the guide crystal
    Exact Raspberry Pi RP2350 hardware-design-guide part (12MHz, 3225-4P,
    CL=10pF, 50ohm, +-30ppm). BOM fully resolved: U1 RP2350A C42411118,
    L1 SMNR4020-2R2UH C135262, Y1 ABM8-272-T3 C20625731.
2026-10-17 fab(rev6.1): JLCPCB-flagged swaps pinned (U7/SW1/SW2/U2/L1/Y1), L1 footprint fix, GND opens fixed, drop regenerated
    - BOM pins exact parts JLCPCB flagged: U7=C114218 Hirose DM3AT-SF-PEJM5,
    SW1/SW2=C269272 C&K KMR221NGLFS, U2=C97521, L1=C135262 SMNR4020,
    Y1=C20625731 ABM8-272-T3 (12MHz 3225 CL=10pF per RP2350 guide)
    - L1: footprint was Bourns SRU5016 5.2x5.2, part is SXN SMNR4020 4x4x2;
    new land pattern pads 3.3x0.95 pitch 3.05 (fix_rev6_l1.py)
    - GND: isolated pads/islands incl. U1-61 thermal pads connected via
    stubs/vias/bridges, zones refilled (fix_rev6_gnd.py)
    - Re-verified on the drop: check_opens = every net single island;
    kicad-cli drc = no electrical violations (cosmetic only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
2026-10-22 fab(rev6.1): pin J5=C49257 header, U7 wording (push-push) + ordering notes from JLCPCB upload round
    - J5 SWD header: pinned C49257 (BOOMELE 2.54-1*3P straight) so the
    BOM auto-matches; any 1x3 2.54mm TH header remains fine
    - U7: corrected push-pull -> push-push (DM3AT is a push-PUSH eject
    socket); noted that C114218 is a JLCPCB Extended part the
    auto-matcher skips - Search/select manually, or hand-solder
    - README records the 2026-10-21 upload round: everything matched
    except J5 (was unpinned) and U7 (Extended part)
2026-10-23 fab(rev6.1): U2 flash package error found (C97521=208mil vs 150mil pads) - BOM corrected, toggle placement images for JLCPCB
    - JLCPCB pre-assembly review flagged U2 package/pad mismatch: C97521
    'W25Q128JVSIQ' is SOIC-8 208mil (JLCPCB part page + Winbond
    datasheet) but board pads are 150mil; error carried since rev5.
    Resolution: option B - U2 unpopulated + refund, flash hand-soldered
    (BOOTSEL UF2 programming works with empty flash). BOM U2 row
    corrected, LCSC cell left blank deliberately; rev7 to move footprint
    to 208mil (TODO.md).
    - JLCPCB also asked for placement clarification of the 12 toggles
    (TH MTS-102/103 lugs onto SMD pads): added annotated renders
    placement-toggles-fu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
2026-11-03 case: one fused print for the shop; toggles mount to the fascia
    - Side gussets fused into the case (gusset_fused = true): fascia, gussets
    and tray print as one solid, no floor bolts. gusset.stl removed;
    gusset_fused = false restores the bolt-on variant.
    - Toggles mount to the fascia, not the board: the body floats in the
    board void, nests in a 13.6 x 8.4 x 2.5 mm back pocket (anti-rotation,
    squared to the void) and a front nut clamps it on a 2.5 mm web. Lugs
    are jumper-wired to the SWD/SWC pads. Replaces the round counterbore.
    - caps.stl generated (12 paddle caps).
    - README/TODO: shop printing notes (SLS/MJF), in-hand checks before
    ordering, and nothing has been printed yet.
